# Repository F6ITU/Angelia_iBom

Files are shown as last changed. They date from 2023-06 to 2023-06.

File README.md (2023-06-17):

# Angelia_iBom
Kicad iBom for OpenHPSDR Angelia SDR main board (reversing)

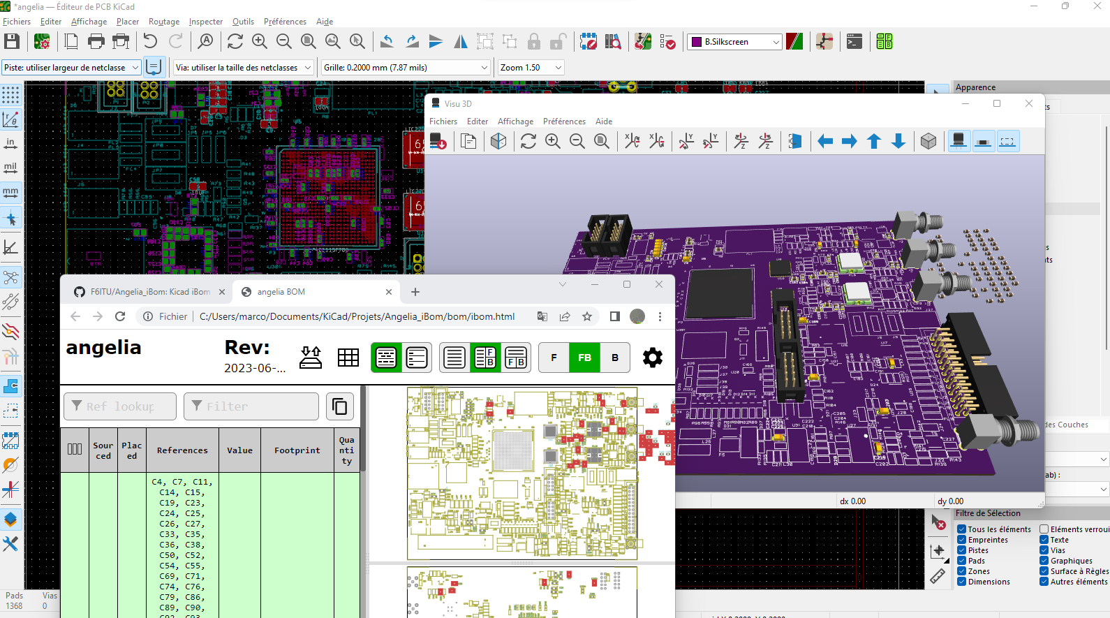
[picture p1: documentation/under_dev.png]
Kicad iBom for OpenHPSDR Angelia


This repository is dedicated to all people wishing to home-built the OpenHPSDR Angelia board. 

This reversing has been done using the official BOM, the original silkmask and the schematic made by the OpenHPSDR group

As most of HPSDR design have been made with a close source EDA (probably Altium), it was necessary to offer an open hardware kind of help 
to the rare and brave people who had the chance to get a grip on a bare Angelia board

This iBom is not fully documented, obvious component placement have been ommited. Feel free to complete the job if you feel yourself 
brave enough 

the 3D picture below gives an idea of the progression
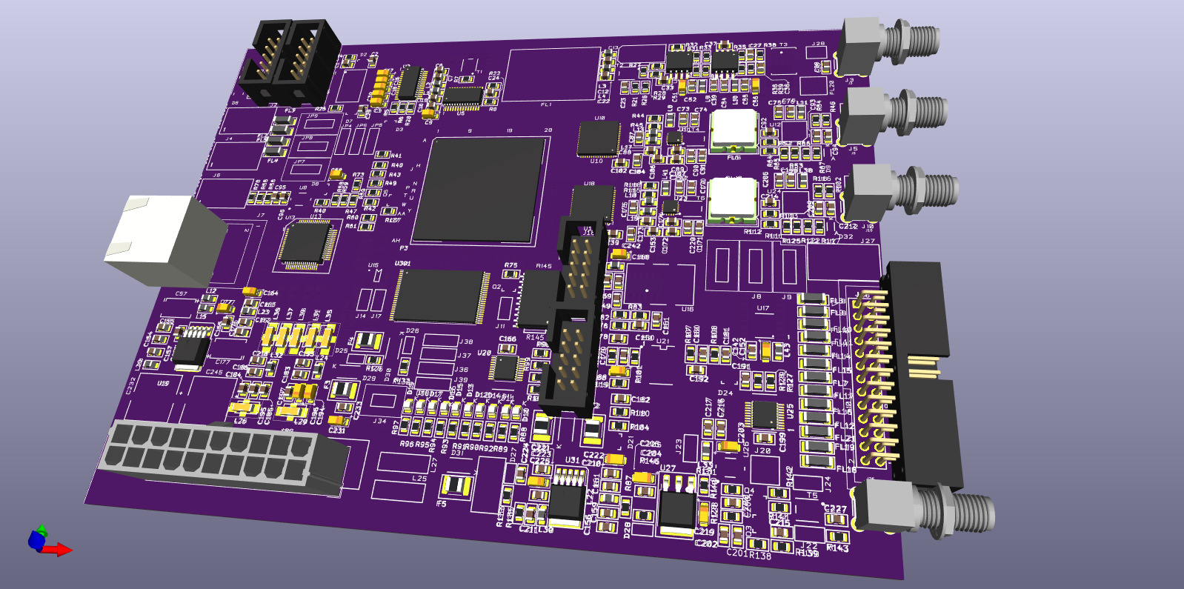
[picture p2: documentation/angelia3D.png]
Kicad angelia virtual board, OpenHPSDR


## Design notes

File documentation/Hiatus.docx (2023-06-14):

Hiatus : C70 absente de la bom, présente silk, sur adc0

Jumelle de C238, 100nF// C 104 ? sur le schéma

C201 placé à coté de C202 comme sur schéma, mais pas de silk pour confirmer

Vérifier C73 C74 et miroir du coté des antialiasing

C201 ??? R138 ??? (138 non marqué, mais très probable)

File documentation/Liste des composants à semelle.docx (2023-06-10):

Liste des composants à semelle, Angelia

FPGA

U21 : TPA0202

U10, U18 : LTC2208CUP (lab)

U11, U23 : LTC6400-20 (lab)

U12, U24 : DAT-31-SP+ (yannick)

U13 : KSZ9021RL

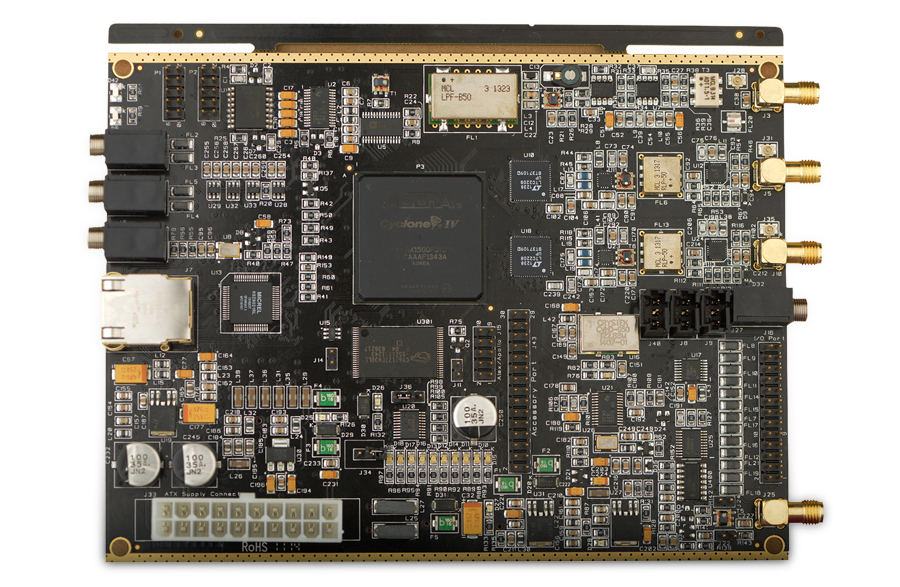
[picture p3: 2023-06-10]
documentation/angelia.jpg

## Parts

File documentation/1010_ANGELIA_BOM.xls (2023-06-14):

Copyright 2012- Apache Labs Pvt Ltd, Angelia Production BOM
Item | CODE | Quantity | Part Number | Reference | format | Part | Manufacturer | Vendor | Vendor Part number | Large Qty no. | remarque | prix | distrib | ref dist. | alternate
1 | A0001 | 30 | T491A106M020AT | C3,C5,C8,C9,C16,C17,C18,C20,C21,C30,C31,C51,C56,C58, C77,C78,C125,C152,C164,C168,C188,C194,C196,C203,C207,C219,C223,C228,C229,C231 | 1206 Kemet T491 | 10UF | Kemet | DigiKey | 399-5152-2-ND | 399-5152-2-ND
2 | A0002 | 80 | C0805X104K1RACTU | C4,C7,C11,C14,C15,C19,C23,C24,C25,C26,C27,C33,C35,C36,C38,C50,C52,C54,C55,C69,C71,C74,C76,C79,C86,C89,C90,C92,C93,C94,C96, C97,C104,C106,C111,C124,C142,C145,C148,C153,C154,C155,C156,C158,C161,C163,C166,C169,C171,C174,C182,C183,C189,C190,C192,C193,C197,C198,C199,C200,C202,C204,C209,C211,C212,C214,C215,C216,C218,C225,C226,C227,C230,C233,C235,C237,C238,C240,C244,C292 | 0805 | 100NF | Kemet | DigiKey | 399-5333-1-ND | 399-5333-2-ND | 80 pieces (par 500 pcs) | 33,5 € | RS | RS 869-5886
3 | A0118 | 2 | 652-CDSOD323-T05LC | D9,D32 | SOD323 | 652-CDSOD323-T05LC | Bourns | Mouser | 652-CDSOD323-T05LC
4 | A0003 | 17 | EXC-CET102U | FL2,FL3,FL4,FL5,FL7,FL8,FL9,FL10,FL11,FL12, FL14,FL15,FL16,FL17,FL18,FL19,FL21 | 1807 | INDUCTOR AUDIO | Panasonic | DigiKey | P9830CT-ND | P9830TR-ND | obsolete
5 | A0004 | 4 | AISC-0805-R047J-T | L13, L17,L18, L19 | 0805 | 47NH | Abracon | DigiKey | 535-10497-1-ND | 535-10497-2-ND
6 | A0005 | 4 | 08055A100JAT2A | C1,C2,C28,C29 | 0805 | 10PF | AVX | DigiKey | 478-1304-1-ND | 478-1304-2-ND
7 | A0006 | 36 | GRM21BR72A103KA01L | C6,C10,C53,C85,C91,C95,C102,C108,C109,C110,C112,C113,C114,C126,C127,C128,C129,C141,C143,C144,C146,C147,C151,C157,C159,C160,C162,C167,C201,C208,C217,C220,C234,C236,C241,C243 | 0805 | 10NF | Murata | DigiKey | 445-1348-1-ND | 445-1348-2-ND
8 | A0007 | 1 | GRM2165C2A201JA01D | C12 | 805 | 200PF | Murata | DigiKey | 490-1606-1-ND | 490-1606-2-ND
9 | A00112 | 1 | SG2020CT-ND | C13 | CV cms | 20PF | Sprague | DigiKey | SG2020CT-ND | SG2020TR-ND
10 | A0008 | 1 | 08055A150JAT2A | C22 | 0805 | 15PF | AVX | DigiKey | 478-1306-1-ND | 478-1306-2-ND
11 | A0009 | 3 | B45197A5476K409 | C32,C57,C177 | 2917 Kemet T495 | 47UF | Kemet | DigiKey | 495-1571-1-ND | 495-1571-2-ND
12 | A0010 | 2 | 08055A330JAT2A | C37,C39 | 0805 | 33PF | AVX | DigiKey | 478-1310-6-ND | 478-1310-2-ND
13 | A0011 | 8 |  | C40,C49,C60,C62,C80,C100,C132,C133 | 0402 | 1NF 0402 | TDK | DigiKey | 445-1256-1-ND | 445-1256-2-ND
14 | A0012 | 33 |  | C41,C43,C44,C45,C46,C47,C48,C61,C63,C64,C65,C66,C67,C68,C81,C83,C84,C98,C99,C101,C115,C116,C117,C118,C119,C120,C122,C123,C134,C135,C137,C138,C139 | 0402 | 100NF 0402 | TDK | DigiKey | 445-4952-1-ND | 445-4952-2-ND | par 500 | 7 | RS | RS 741-4415
15 | A0013 | 8 |  | C42,C59,C82,C121,C130,C131,C136,C140 | 0402 | 10NF 0402 | TDK | DigiKey | 445-1260-1-ND | 445-1260-2-ND
16 | A0014 | 6 | C2012C0G1H102J | C70,C103,C179,C180,C239,C242 | 0805 C0G | 1NF(1000PF) | TDK | DigiKey | 445-1330-1-ND | 445-1330-2-ND
17 | A0014 | 6 | C2012C0G1H102J | C72,C73,C107,C170,C172,C251 | 0805 C0G | 1000PF | TDK | DigiKey | 445-1330-1-ND | 445-1330-2-ND
18 | A0016 | 6 | C0805C101J5GACTU | C75,C87,C105,C173,C175,C206 | 0805 C0G | 100PF | Kemet | DigiKey | 399-1122-1-ND | 399-1122-2-ND
19 | A0017 | 2 | TMK212B7225KG-TR | C88,C213 | 0805 | 2.2UF | Taiyo Yuden | DigiKey | 587-2991-2-ND | 587-2991-2-ND
20 | A0018 | 1 | GRM21BR71E334KA01L | C149 | 0805 | 330NF | Murata | DigiKey | 490-1677-1-ND | 490-1677-2-ND
21 | A0019 | 1 | 08055C473KAT2A | C150 | 0805 | 47NF | AVX | DigiKey | 478-1391-1-ND | 478-1391-2-ND
22 | NR | 7 | EMK212BJ106KG-T | C165,C176,C178,C181,C184,C186,C195 | 0805 | 10UF | TDK | DigiKey | 445-7534-1-ND | 445-7534-2-ND | la référence digikey est celle de 100 nF
23 | NR | 1 |  | C185 | 0805 | (10UF) | Murata | DigiKey | 478-1391-1-ND | 478-1391-2-ND | la référence digikey est celle de 470 nF
24 | A0022 | 4 |  | C187,C210,C221,C224 | 0805 | 1UF | TDk | DigiKey | 445-1354-1-ND | 445-1354-2-ND
25 | A0023 | 1 | GRM2165C1H471JA01D | C191 | 0805 | 470PF | Murata | DigiKey | 490-1617-1-ND | 490-1617-2-ND
26 | A0024 | 2 | TAJA105K025RNJ | C205,C222 | 1206 | 1UF | AVX | DigiKey | 478-2363-1-ND | 478-2363-2-ND
27 | A0120 | 2 |  | C232,C245 | 0.394" Dia (10.00mm) | 100UF | Panasonic | DigiKey | PCE3949TR-ND | PCE3949TR-ND
28 | A0025 | 2 | BAT54C-G | D2,D7 | SOT23 | BAT54C | Comchip | DigiKey | 641-1320-1-ND | 641-1320-2-ND
29 | A0026 | 1 | BAT54S-TP | D3 | SOT23 | BAT54S | Micro Commercial | DigiKey | BAT54STPMSCT-ND | BAT54STPMSTR-ND
30 | A0027 | 3 | BAT54-TP | D4,D5,D24 | SOT23 | BAT54 | Micro Commercial | DigiKey | BAT54TPMSCT-ND | BAT54TPMSTR-ND
31 | A0028 | 2 | LS Y876-Q2S1-1-Z | D6,D42 | 2-SMD, Flat Lead | FRONT LED | Osram | DigiKey | 475-2769-1-ND | 475-2769-2-ND
32 | A0029 | 1 | BAT54A-G | D8 | SOT23 | BAT54A/SOT | Comchip | DigiKey | 641-1319-1-ND | 641-1319-2-ND
33 | A0030 | 10 | APT2012SURCK | D10,D11,D12,D13,D14,D15,D16,D17,D18,D19 | 0805 (led) | RED LED | Kingbright | DigiKey | 754-1133-1-ND | 754-1133-2-ND
34 | A0031 | 4 | MBRA340T3G | D20,D29,D30,D31 | DO-214AC, SMA | MBRA340T3G | ON Semi | DigiKey | MBRA340T3GOSCT-ND | MBRA340T3GOSTR-ND
35 | A0032 | 1 | BZX84C3V3-TP | D21 | SOT23-3 | BZX84C 3V3 | Diodes Inc | DigiKey | BZX84C3V3-FDICT-ND | BZX84C3V3-FDITR-ND
36 | A0033 | 4 |  | D25,D26,D27,D28 | 0805 | GREEN LED | Lite-On | DigiKey | 160-1423-1-ND | 160-1423-2-ND
37 | A00121 | 1 |  | FL1 | : HZ1198 | LPF-B50+ |  | MCL | LPF-B50+ | LPF-B50+ |  | 16,95 $ | MCL
38 | A00125 | 2 | RLP-50+ | FL6,FL13 | GP731 | RLP-50+ |  | MCL | RLP-50+ | RLP-50+ |  | 7,95 $ | MCL
39 | A00127 | 1 | LFCV-52+ | FL20 | JV1210C | LFCV-52+ |  | MCL | LFCV-52+ | LFCV-52+ |  | 3,99 $ | MCL
40 | A0034 | 4 |  | F1,F2,F4,F5 | 1812 | 2A FUSE | Bel Fuse | DigiKey | 507-1508-1-ND | 507-1508-2-ND | change selon protocol 2
41 | A00113 | 7 |  | JP4,JP5,JP6,J36,J37,J38,J39 |  | 3 PIN BERG | Molex | Digikey | 609-3461-ND | 609-3461-ND
42 | A0035 | 5 |  | JP7,JP8,J8,JP9,J9 |  | 3 PIN CONNECTOR | TE | DigiKey | A28477-ND | A28477-ND
43 | A0036 | 4 |  | J2,J4,J6,J27 |  | 3.5MM AUDIO | CUI | DigiKey | CP1-3533N-ND | CP1-3533N-ND
44 | A0037 | 4 |  | J3,J5,J10,J25 | SMA Angle | SMA | TE | DigiKey | A97593-ND | A97593-ND
45 | A0038 | 1 |  | J7 | RJ45 (voir hermeslite) | RJ45 | TE Connectivity | DigiKey | A99638-ND | A99638-ND |  | 12,41 $ | DGK |  | Farnell (ref alternative 1572188
46 | A0039 | 6 |  | J11,J14,J17,J22,J23,J24 |  | HEADER 2 | FCI | DigiKey | 609-4434-ND | 609-4434-ND
47 | A0040 | 4 |  | P1,P2,J15,J18 |  | 5X2 BERG | FCI | DigiKey | 609-3458-ND | 609-3458-ND
48 | A00111 | 1 | DNI | J16 |  | IO HEADER | FCI | DigiKey | 609-3240-ND | 609-3240-ND
49 | A0039 | 1 |  | J20 |  | JUMPER 10Mhz SELECT | FCI | DigiKey | 609-4434-ND
50 | A0042 | 3 |  | J28,J31,J35 | ufl | MICRO COAXIAL | Molex | DigiKey | WM5587CT-ND | WM5587CT-ND
51 | A0043 | 1 |  | J33 | conn ATX | ATX Connector | Molex | DigiKey | WM7346-ND | WM7346-ND
52 | NR | 1 | DNI | J34 |  | POWER SWITCH
53 | A00113 | 1 |  | J40 (PCB LOCATION NOT FOUND) |  | CLK OUT
54 | A0044 | 25 |  | L1,L2,L6,L8,L9,L10,L11,L12,L14,L15,L16,L20,L21,L22,L23,L24,L30,L32,L33,L38,L41,L42,L43,L44,L45 | 0805 | MPZ2012S221A | TDK | DigiKey | 445-1568-1-ND | 445-1568-2-ND
55 | A0045 | 1 |  | L3 | 0805 | 560nH 5% | Panasonic | DigiKey | PCD1181CT-ND |  | obsolete r (qtt 5==> | 0,576 € | RS | 871-1985 | NFM41PC204F1H3L
56 | A0046 | 1 |  | L4 | 0805 | 22nH | Sumida | DigiKey | 308-1733-1-ND | 308-1733-1-ND | non stocké
57 | NR | 2 |  | L25,L27 | 2-SMD, J-Lead | 2743021447 | Fair-Rite | Mouser | 623-2743021447LF
58 | A0047 | 7 |  | L26,L29,L31,L35,L36,L37,L39 | 1806 | NFM41PC204F1H3L | Murata | DigiKey | 490-2550-1-ND | 490-2550-2-ND
59 | A0128 | 1 |  | P3 | 780FBGA | EP4CE115F780 | Altera | DigiKey | 544-1471-ND | 544-1471-ND | faible stock dgk | 341,36 $ |  |  | mouser farnell avnet
60 | A0048 | 2 |  | Q2,Q5 | SOT23-3 | 2N7002K | Fairchild | DigiKey | 2N7002KCT-ND | 2N7002KTR-ND
61 | A0049 | 2 |  | Q3,Q4 | SOT23-3 | MMBT3906 | Diodes Inc | DigiKey | MMBT3906-FDICT-ND | MMBT3906-FDITR-ND
62 | A0050 | 36 |  | R2,R10,R40,R41,R42,R50,R52,R53,R54,R58,R64,R65,R66,R67,R68,R69,R70,R71,R72,R75,R78,R82,R106,R108,R111,R112,R113,R114,R116,R117,R122,R123,R124,R125,R136,R137 | 0805 | 10K | Vishay | DigiKey | 541-10.0KCCT-ND | 541-10.0KCTR-ND
63 | A0051 | 16 |  | R3,R16,R21,R26,R43,R48,R49,R61,R79,R85,R103,R109,R120,R121,R130,R133 | 0805 | 1K | Vishay | DigiKey | 541-1.00KCCT-ND | 541-1.00KCTR-ND
64 | A0052 | 6 |  | R4,R25,R28,R29,R33,R34 | 0805 | 22E | Vishay | DigiKey | 541-22.0CCT-ND | 541-22.0CTR-ND
65 | A0053 | 13 |  | R5,R6,R88,R89,R90,R91,R92,R93,R94,R95,R96,R97,R132 | 0805 | 2K2 | Panasonic | DigiKey | P2.20KCCT-ND | P2.20KCTR-ND
66 | A0054 | 7 |  | R7,R44,R45,R115,R118, R141,R143 | 0805 | 51E | Yageo | DigiKey | 311-51ARCT-ND | 311-51ARTR-ND
67 | A0055 | 1 |  | R8 | 0805 | 1K8 | Vishay | DigiKey | 541-1.80KCCT-ND | 541-1.80KCTR-ND
68 | A0056 | 1 |  | R9 | 0805 | 18K | Vishay | DigiKey | 541-18.0KCCT-ND | 541-18.0KCTR-ND
69 | A0057 | 2 |  | R11,R12 | 0805 | 510K | Vishay | DigiKey | 541-510KCCT-ND | 541-510KCTR-ND
70 | A0058 | 3 |  | R13,R14,R15 | 0805 | 100K | Vishay | DigiKey | 541-100KCCT-ND | 541-100KCTR-ND
71 | A0059 | 2 |  | R19,R51 | 0805 | 1K5 | Vishay | DigiKey | 541-1.50KCCT-ND | 541-1.50KCTR-ND
72 | A0060 | 5 | CRCW08053K30FKEA | R20,R76,R129,R138,R140 | 0805 | 3K30 | Vishay | DigiKey | 541-3.30KCCT-ND | 541-3.30KCTR-ND
73 | A0061 | 2 |  | R22,R24 | 0805 | 100E | Vishay | DigiKey | 541-100CCT-ND | 541-100CTR-ND
74 | A0062 | 1 |  | R23 | 0805 | 220K | Panasonic | DigiKey | P220KCCT-ND | P220KCTR-ND
75 | A0063 | 1 |  | R27 | 0805 | 200E | Vishay | DigiKey | 541-200CCT-ND | 541-200CTR-ND
76 | A0064 | 2 |  | R30,R31 | 0805 | 330E | Vishay | DigiKey | 541-330CCT-ND | 541-330CTR-ND
77 |  | 4 |  | R32,R55,R56,R127 | 0805 | 220E | Vishay | DigiKey | 541-180CCT-ND | 541-180CTR-ND
78 | A0066 | 4 |  | R35,R36,R37,R146 | 0805 | 470E | Vishay | DigiKey | 541-470CCT-ND | 541-470CTR-ND
79 | A0067 | 2 |  | R38,R39 | 0805 | 4.7E | Vishay | DigiKey | 541-4.70CCCT-ND | 541-4.70CCTR-ND
80 | A0068 | 2 |  | R46,R102 | 0805 | 1M | Vishay | DigiKey | 541-1.00MCCT-ND | 541-1.00MCTR-ND
81 | A0069 | 9 |  | R47,R60,R77,R84,R86,R87,R119,R131,R135 | 0805 | 0E | Vishay | DigiKey | 541-0.0ACT-ND | 541-0.0ATR-ND
82 | A0070 | 1 |  | R57 | 0805 | 4K99 | Vishay | DigiKey | 541-4.99KCCT-ND | 541-4.99KCTR-ND
83 | A0071 | 3 |  | R59,R73,R104 | 0805 | 4K7 | Vishay | DigiKey | 541-4.70KCCT-ND | 541-4.70KCTR-ND
84 | A0072 | 3 |  | R83,R101,R107 | 0805 | 47K | Vishay | DigiKey | 541-47.0KCCT-ND | 541-47.0KCTR-ND
85 | A0073 | 4 |  | R98,R99,R100,R105 | 0805 | 33E | Vishay | DigiKey | 541-33.0CCT-ND | 541-33.0CTR-ND
86 | A0074 | 2 |  | R110,R126 | 0805 | 820E | Vishay | DigiKey | 541-820CCT-ND | 541-820CTR-ND
87 | A0075 | 0 |  |  | 0805 | 6K8 | Vishay | DigiKey | 541-6.80KCCT-ND | 541-6.80KCTR-ND
88 | A0076 | 1 |  | R142 | 0805 | 150E | Panasonic | DigiKey | P150CCT-ND | P150CCT-ND
89 | A0077 | 1 |  | R145 | 20SOIC | SOMC100KPCT-ND | Vishay | DigiKey | SOMC100KPCT-ND | SOMC100KPCT-ND
90 | A00123 | 2 |  | T1,T5 | AT224-1A | TC1-1T | MCL | MCL | TC1-1T+ | TC1-1T+ |  | 2,19 $ | MCL
91 | A00122 | 3 |  | T2,T4,T6 | AT224-1A | TC4-1T | MCL | MCL | TC4-1T+ | TC4-1T+ |  | 2,19 $ | MCL
92 | A00126 | 1 |  | T3 | AT224-1A | ADT1.5-1 | MCL | MCL | ADT1.5-1+ | ADT1.5-1+ |  | 14,95 $ | MCL
93 | A00129 | 1 |  | U1 |  | EPCS128 | ALTERA | plusieurs | ref, attention | EPCS128 | EPCS64 REC
94 | A0078 | 1 |  | U2 | 28-TSSOP | TLV320AIC23B | TI | Digikey | 296-15031-1-ND | 296-15031-1-ND | samples TI | 8.69 $ | DGK
95 | A0079 | 2 |  | U3,U4 | 8SOIC | LMC6482AM | National | DigiKey | LMC6482IM-ND | LMC6482IM-ND |  | 1,19 € | rs-comp | RS 534-4153 | arrow
96 | A0080 | 1 |  | U5 | 28TSSOP | AD9744ARU | AD | DigiKey | AD9744ARUZ-ND | AD9744ARUZ-ND | fin de vie | 17,67 $ | DGK |  |  | attention, composant rare
97 | A0081 | 2 |  | U6,U7 | 8SOIC | OPA2674IC | TI | DigiKey | 296-15212-5-ND | 296-15212-5-ND | samples TI | 4,15 $ | DGK
98 | A0117 | 1 |  | U8 | 4-SMD, No Lead (tcxo) | 25MHZ | Fox | DigiKey | 631-1074-1-ND | 631-1074-2-ND |  | 2,71 $ | DGK |  | Farnell, elt 14
99 | A0084 | 2 |  | U10,U18 | 64QFN | LTC2208CUP | LTC2208CUP | NU HORIZON | LTC2208CUP#PBF | LTC2208CUP#PBF-ND | samples LT
100 | A0085 | 2 |  | U11,U23 | 16QFN | LTC6400-20 | LTC6400-20 | NU HORIZON | LTC6400CUD-20#PBF | LTC6400CUD-20#PBF-ND | samples LT
101 | A00124 | 2 |  | U12,U24 | DG983-2 (qfn 20) | DAT-31-SP+ | MCL | MCL | DAT-31-SP+ | DAT-31-SP+ | DAT-31A-SP+ | 3,55 $ | MCL |  |  | This is a non-catalog model
102 | A0086 | 1 |  | U14 | 14SOIC | SN65LVDM180D | TI | DigiKey | 296-1420-5-ND | 296-1420-5-ND |  | 3,39$ | DGK |  | Farnell mouser
103 |  | 1 |  | U15 | SOT23-6 | 25AA02E48T-I/OT | Microchip | DigiKey | 25AA02E48T-I/OTCT-ND | 25AA02E48T-I/OTCT-ND |  | 0,32€ | rs-comp | RS 667-8347
104 | A0088 | 1 |  | U16 | oscillateur crystek | 122.88MHZ | Crystek | DigiKey | 744-1271-ND | 744-1271-ND |  | 33,46 $ | DGK |  | mouser 549-CVHD-950-122.880 (22,9 € | remplacé par CVHD-37x
105 | A0089 | 1 |  | U17 | 16-TSSOP large? | ADC78H90CIMT | National | DigiKey | ADC78H90CIMT-ND | ADC78H90CIMT-ND | samples TI | 6,31€ | Farnell | 2496158 |  | rupure
106 | A0090 | 2 |  | U19,U31 | TO-252-5, DPak (4 Leads + Tab), TO-252AD | LD49300PT12R | STM | DigiKey | 497-8277-1-ND | 497-8277-1-ND |  | 2,32 $ | DGK |  | mouser
107 | A0091 | 2 |  | U20,U25 | 20TSSOP | 74LCX541 | Fairchild | DigiKey | 74LCX541MTC-ND | 74LCX541MTCXTR-ND |  | 0,38 € | rs-comp |  | qté de 10
108 | A0092 | 1 |  | U21 | 24HTSSOP | TPA0202 | TI | DigiKey | 296-1940-5-ND | 296-1940-5-ND |  | 4,45 $ | DGK |  | Mouser, TI store
109 | A0093 | 1 |  | U22 | SOIC 16 | ULN2003AD | TI | DigiKey | 296-1368-5-ND | 296-1368-2-ND |  |  |  |  | voir RS, en qté
110 | A0094 | 1 |  | U24 -U13? | 64-LQFP-EP | KSZ9021RL | Micrel | DigiKey | 576-3636-ND | 576-3636-ND |  | 9,77€ | rs-comp | RS 911-2717
111 | A0095 | 1 |  | U26 | xtal idem | 10MHZ 3.2X5MM | Fox | DigiKey | 631-1067-1-ND | 631-1067-2-ND |  | 2,34 $ | DGK |  | farnell mouser
112 | A0096 | 1 |  | U27 | TO252-3 | LD1117-2.5V | Diodes Inc | DigiKey | ZLDO1117K25DICT-ND | ZLDO1117K25DICT-ND |  | 0,59 $ | DGK |  | mouser
113 | A0097 | 1 |  | U301 | 48-TFSOP | CY62177EV30LL-55ZXI-ND | CY62177EV30LL-55ZXI | ARROW | CY62177EV30LL-55ZXI | CY62177EV30LL-55ZXI-ND |  | 35,35€ | rs-comp | RS 726-0209
114 | A0098 | 1 |  | F3 | 1812 | O0ZCC0300FF2B | O0ZCC0300FF2B | BEL FUSE | 507-1513-1-ND | 507-1513-1-ND
 |  | 2 |  | R128, R139 |  | 5K11 |  |  |  |  | probablement ligne 87
 |  | 556

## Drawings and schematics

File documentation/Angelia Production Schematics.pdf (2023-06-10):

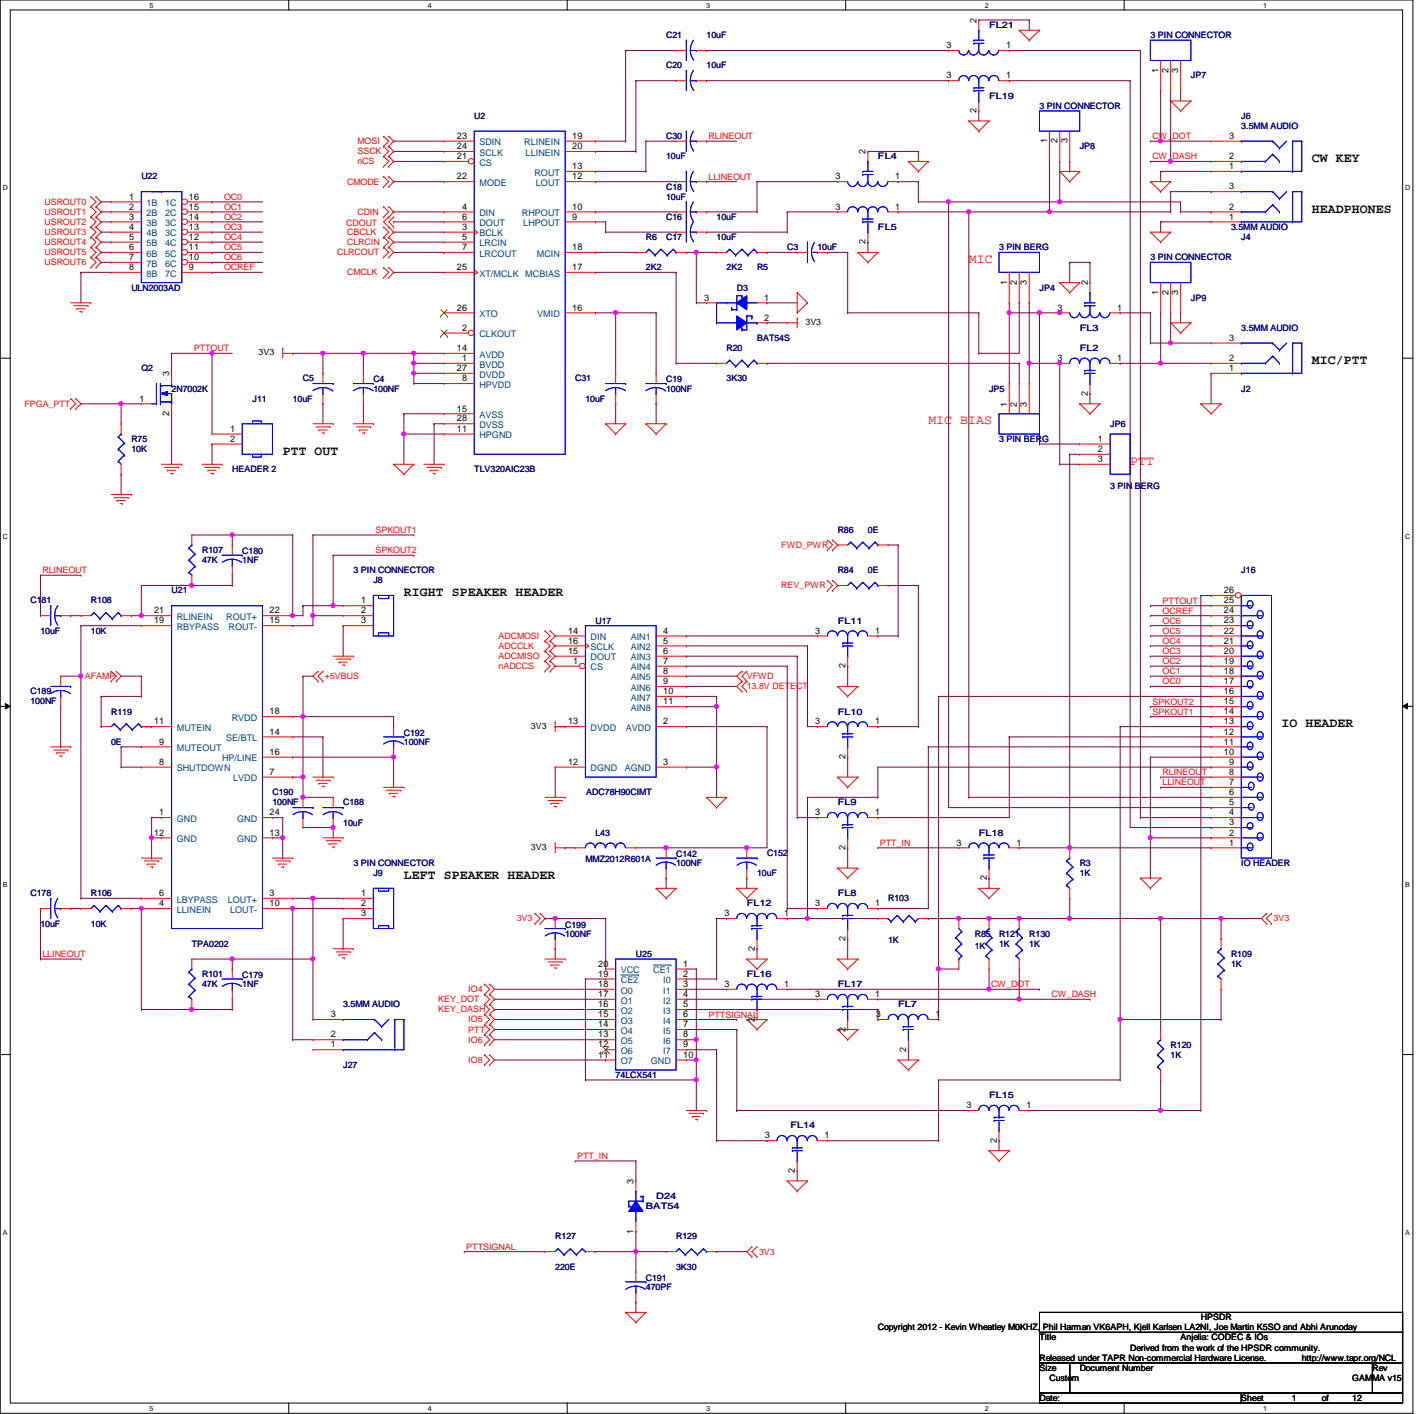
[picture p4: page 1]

Copyright 2012 - Kevin Wheatley M0KHZ, Phil Harman VK6APH, Kjell Karlsen LA2NI, Joe Martin K5SO and Abhi Arunoday

Derived from the work of the HPSDR community.

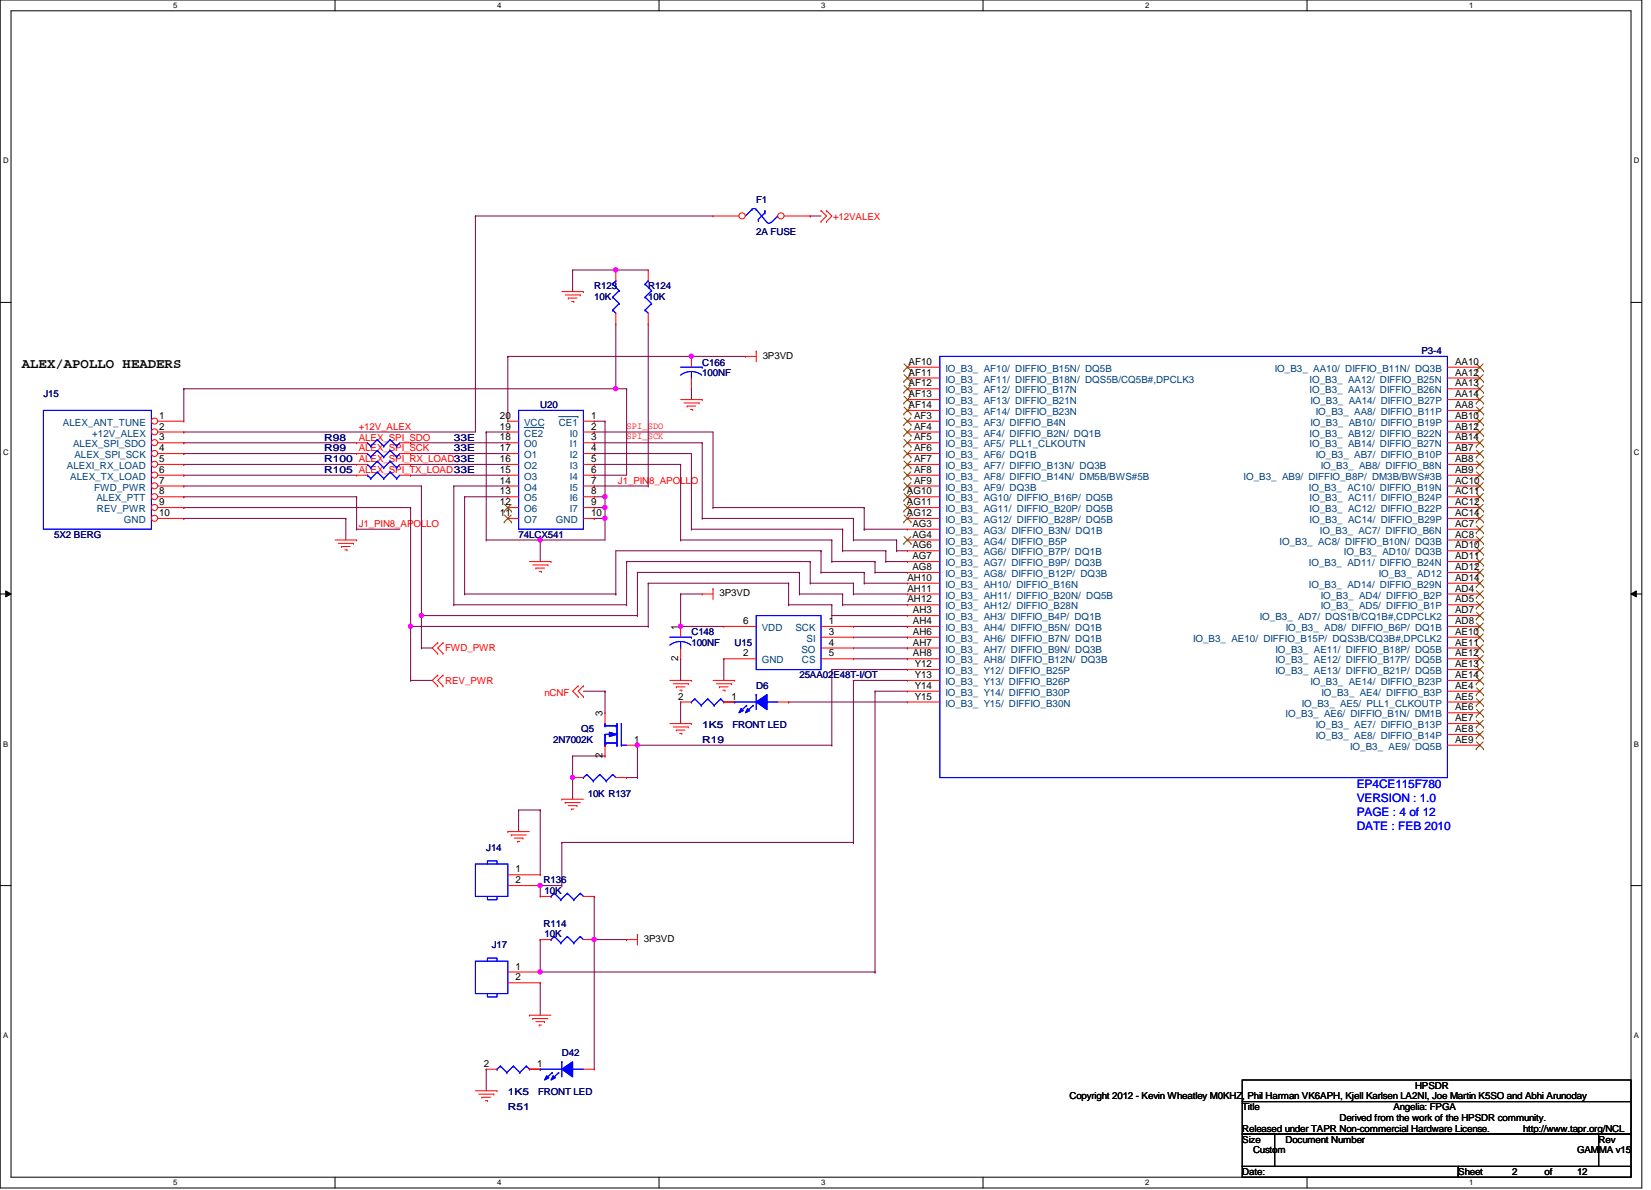
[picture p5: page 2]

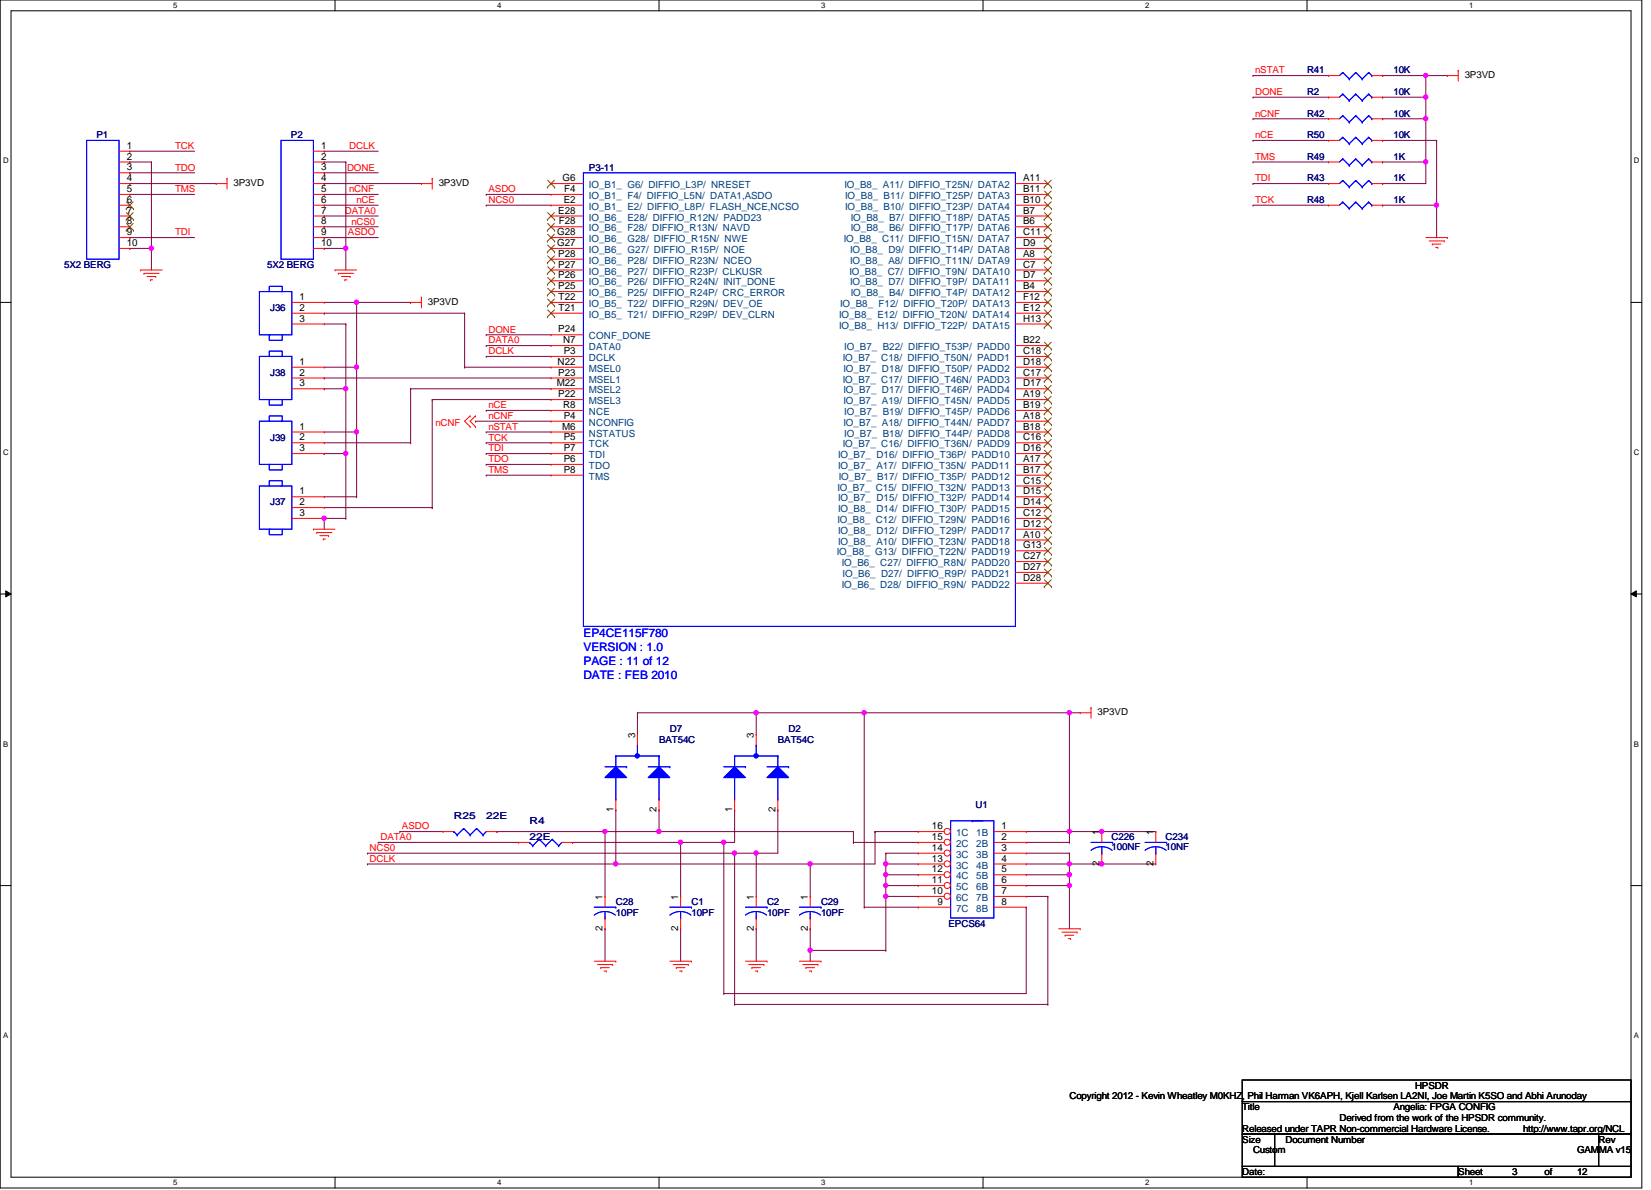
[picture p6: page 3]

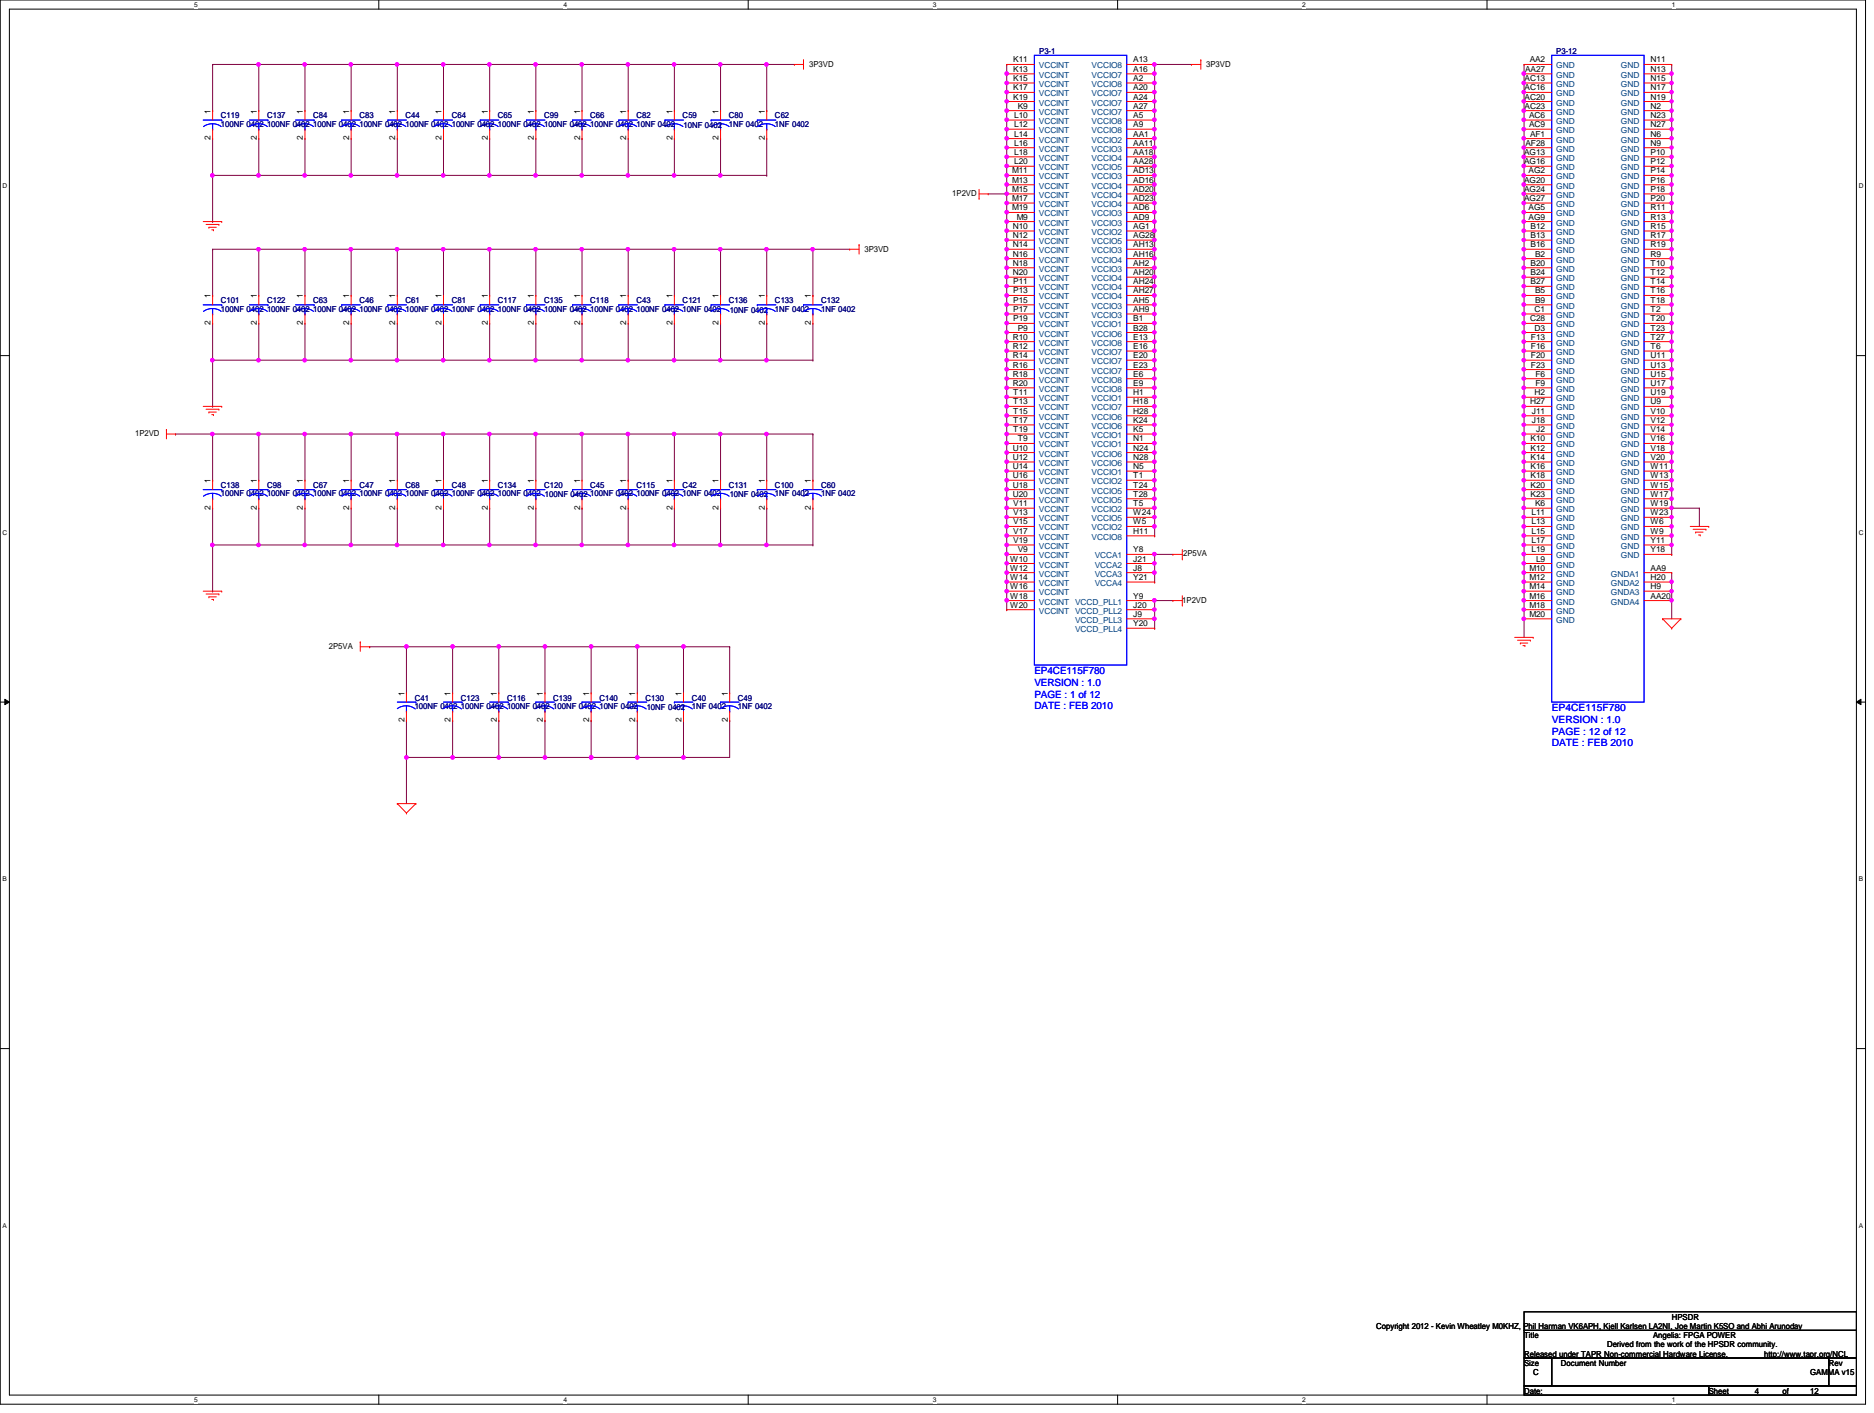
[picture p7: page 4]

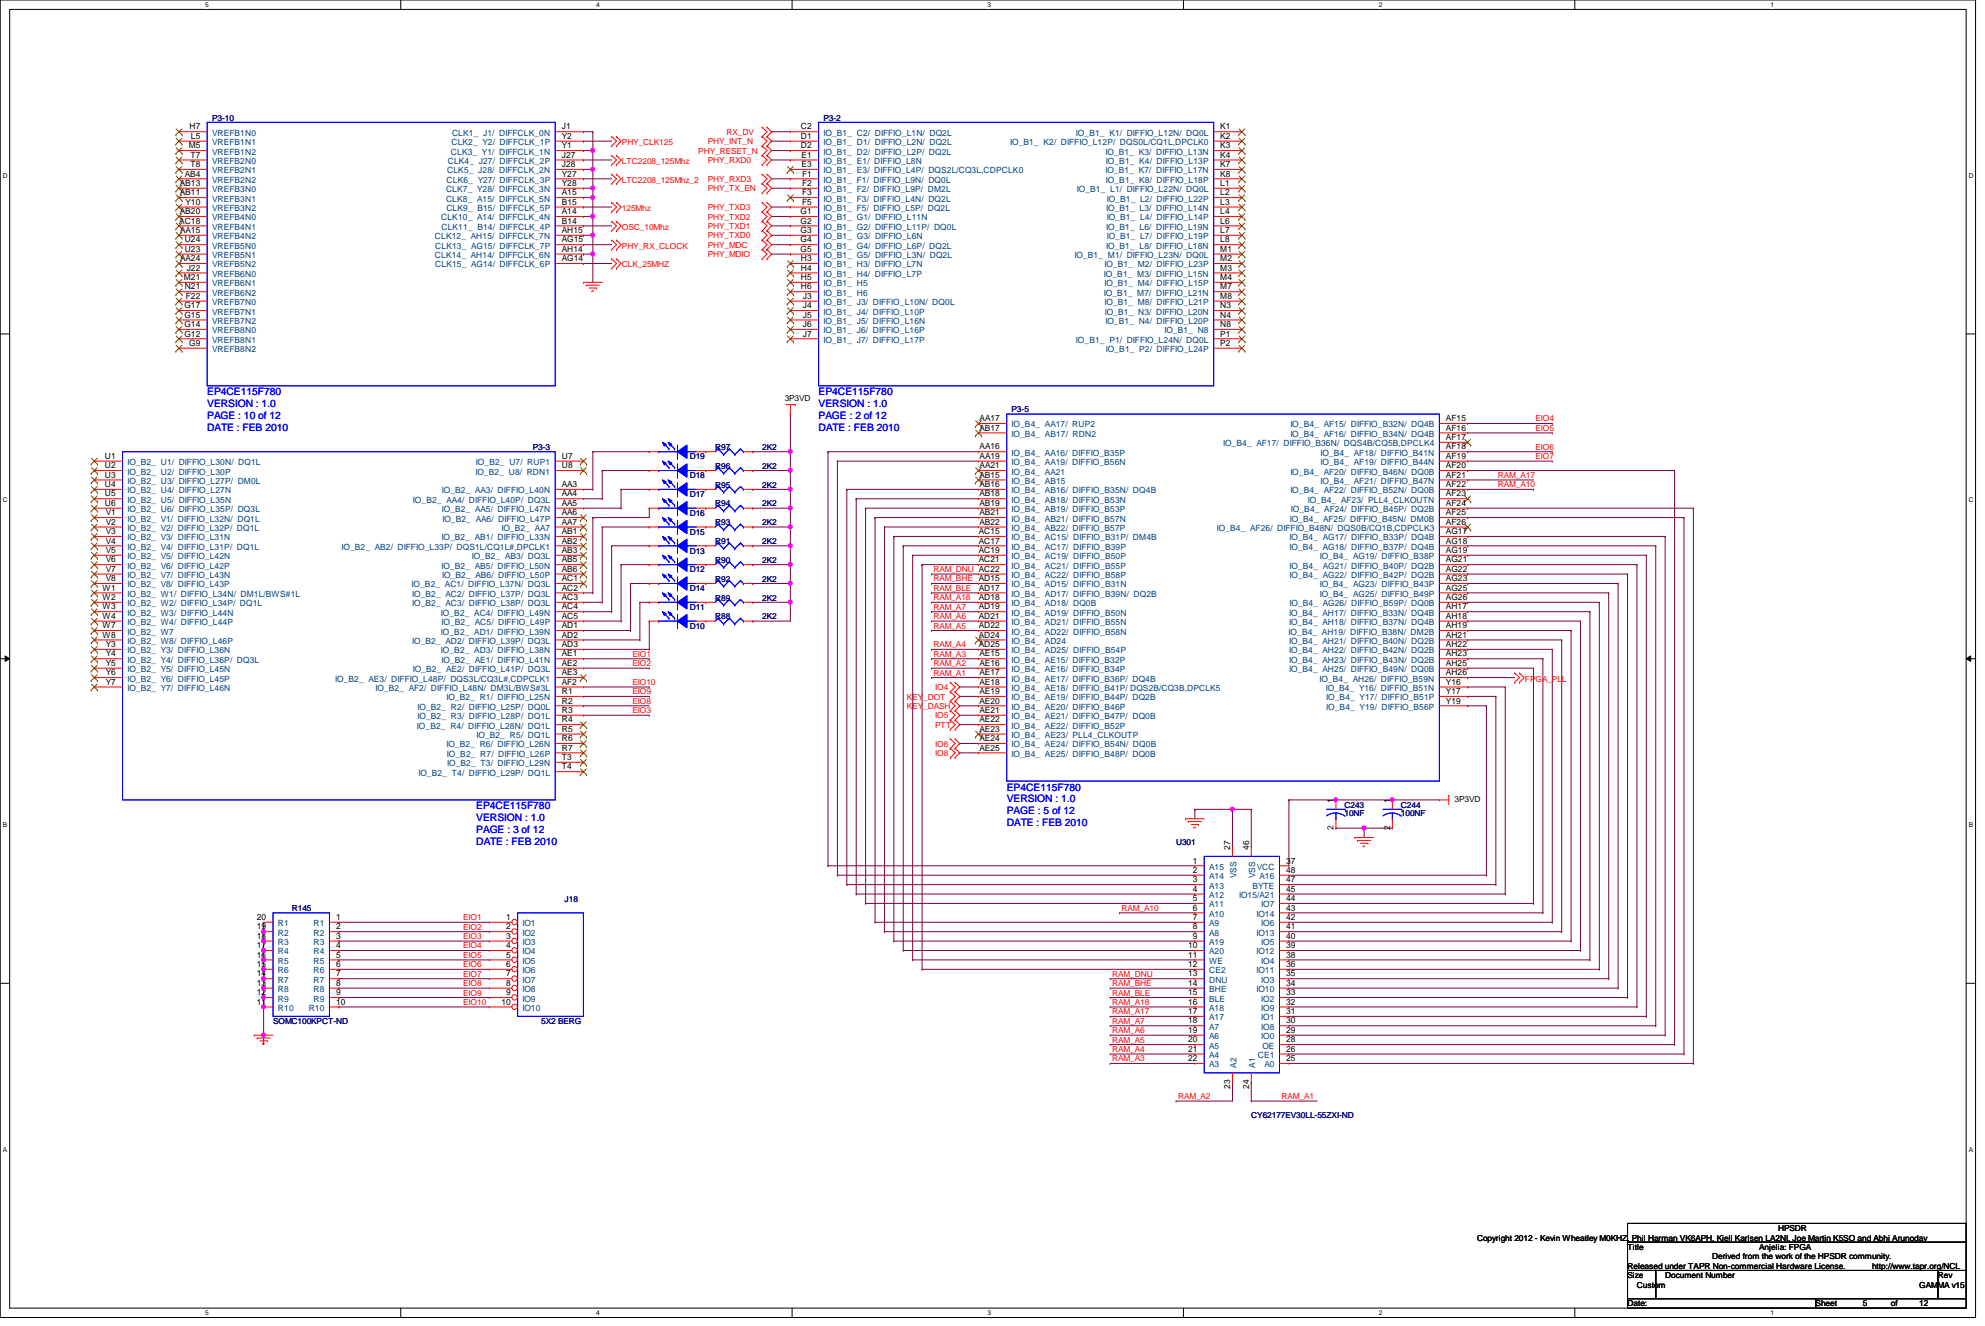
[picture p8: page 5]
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

Derived from the work of the HPSDR community.

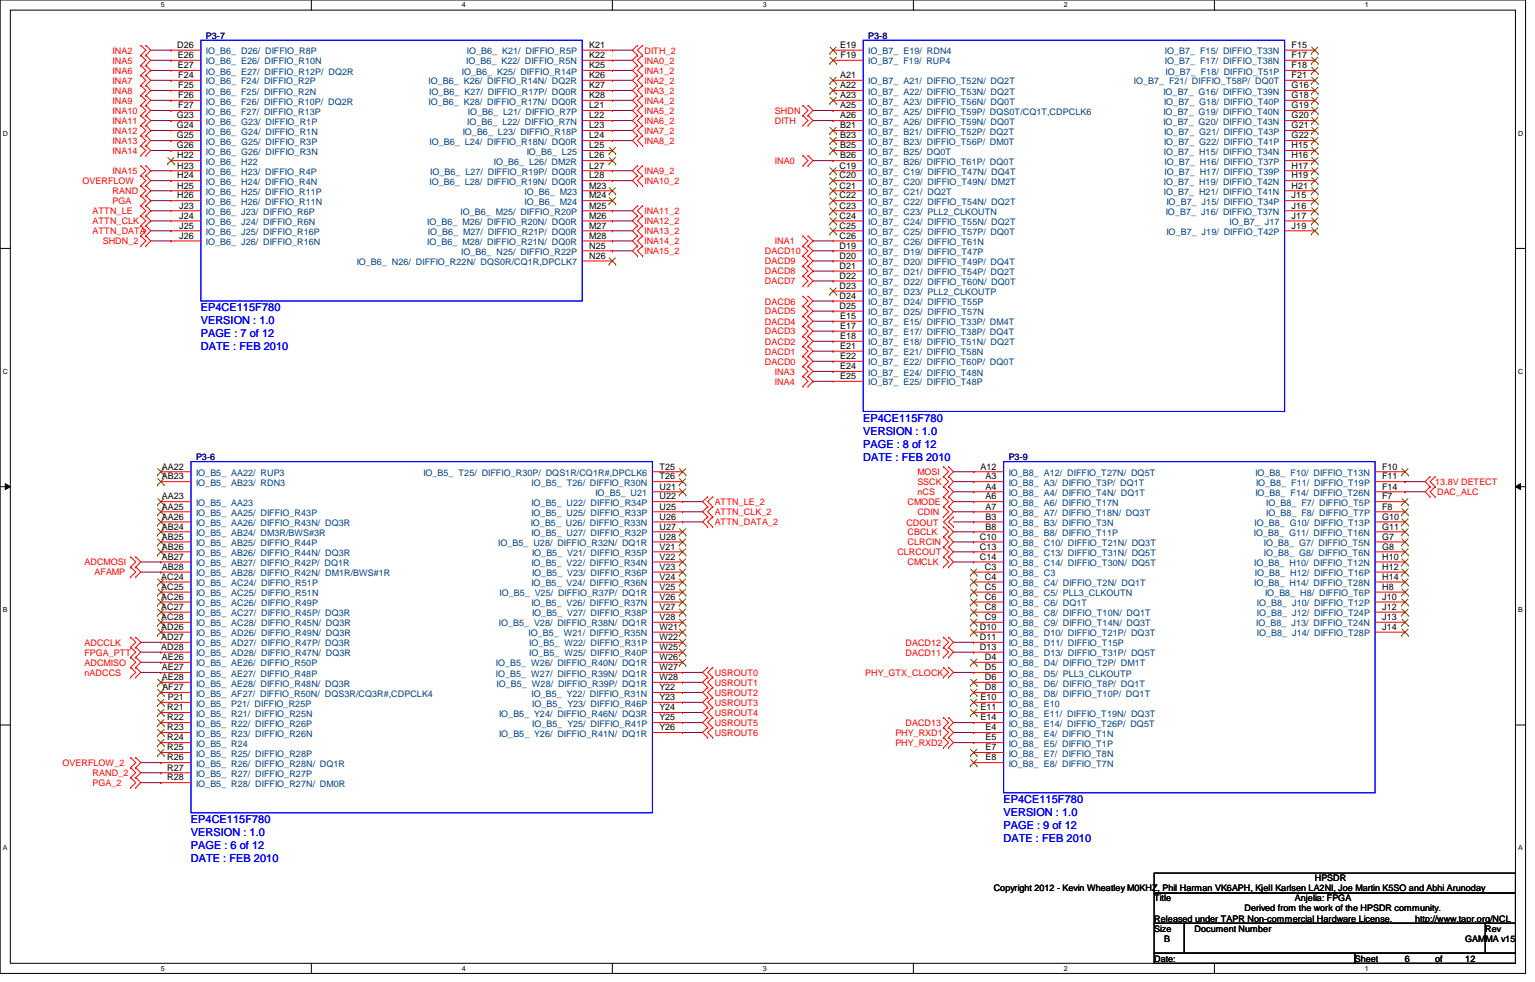
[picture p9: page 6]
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

Derived from the work of the HPSDR community.

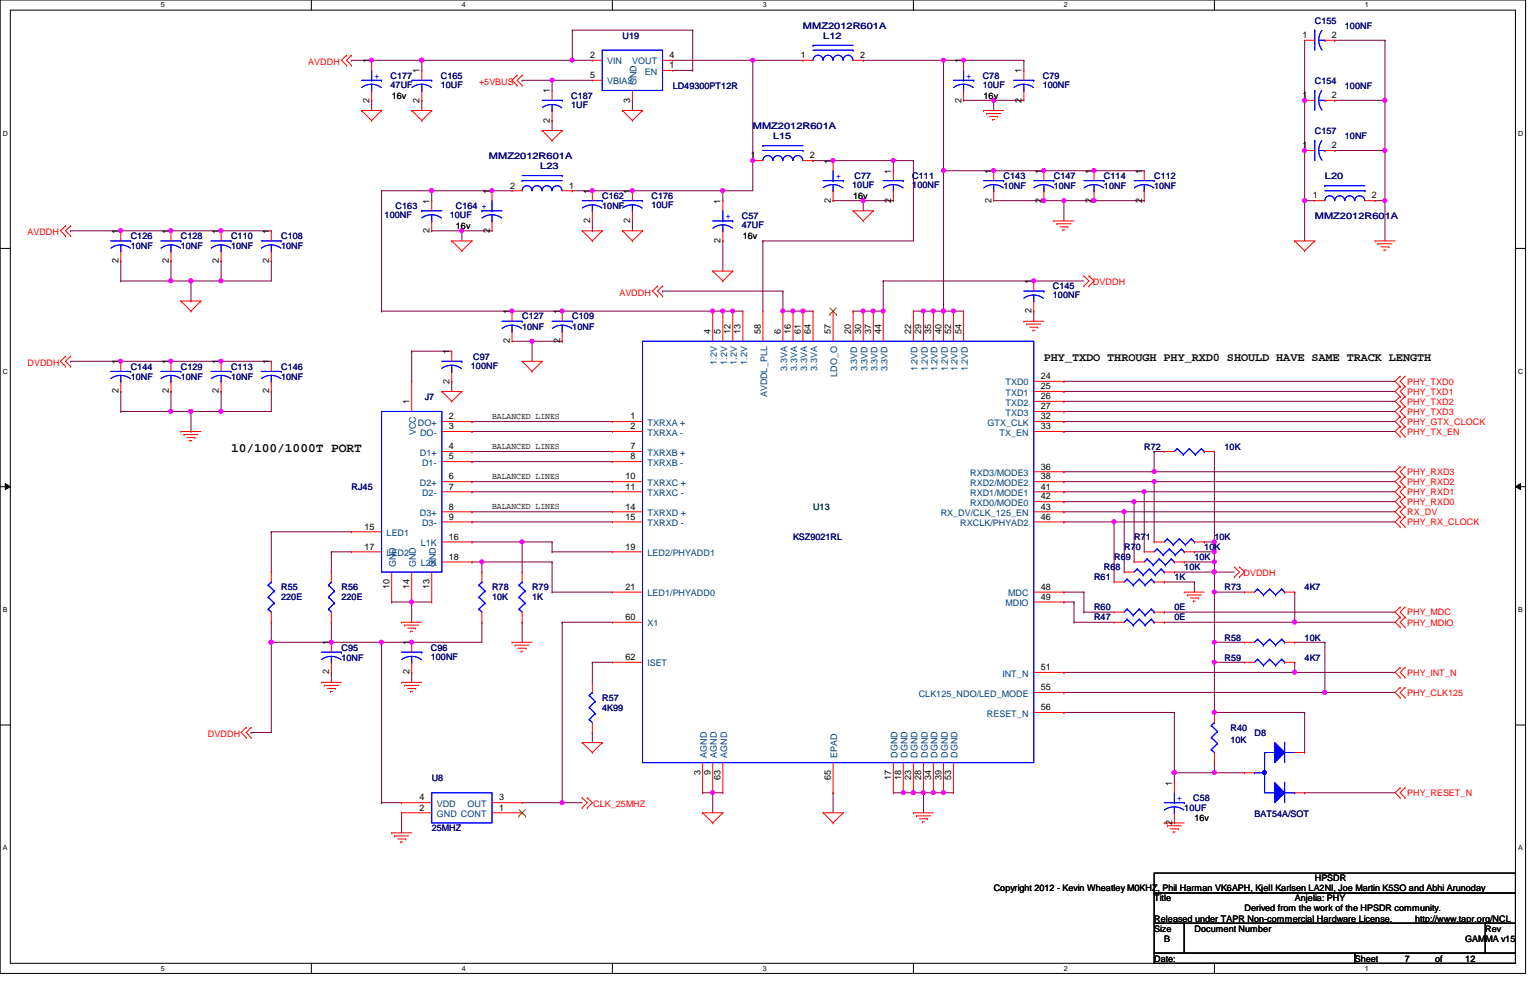
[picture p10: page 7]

PHY_TXDO THROUGH PHY_RXD0 SHOULD HAVE SAME TRACK LENGTH

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

Derived from the work of the HPSDR community.

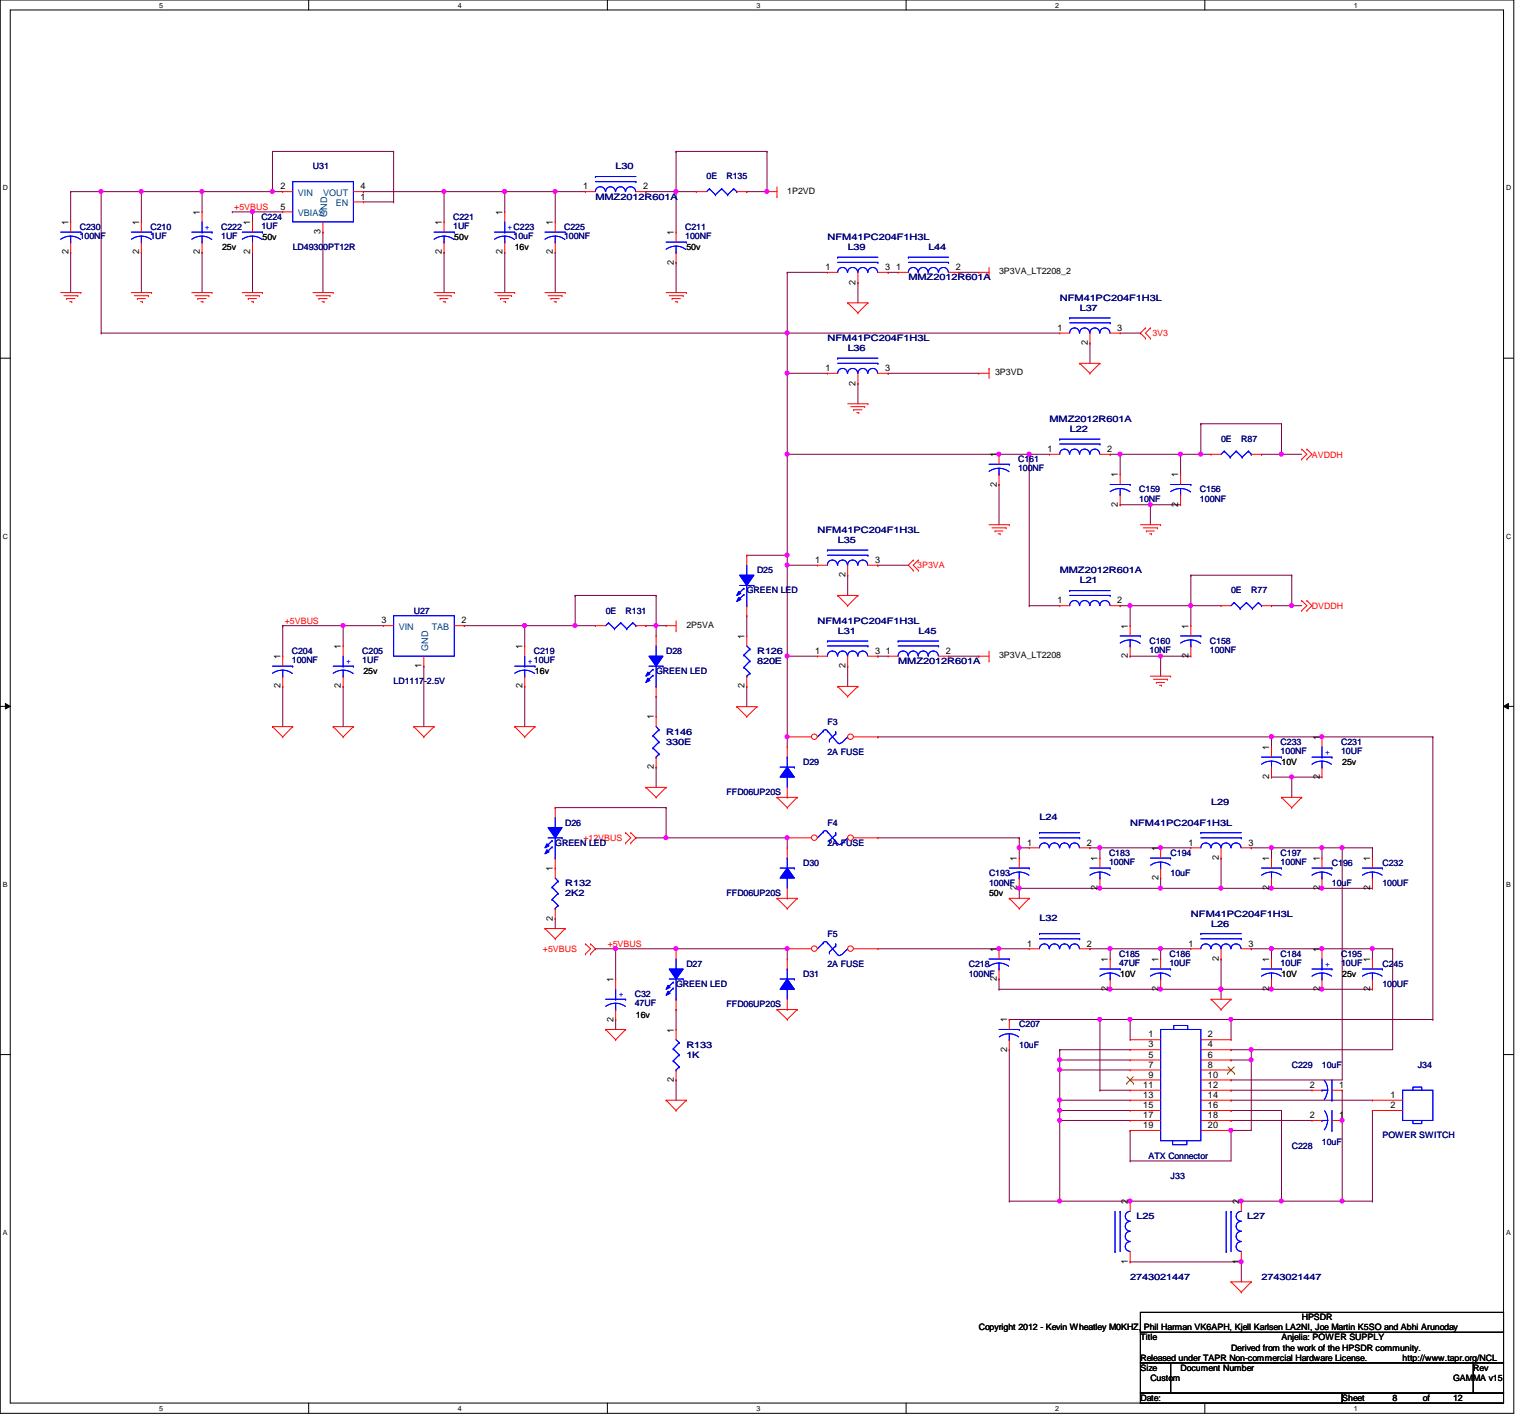
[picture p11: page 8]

17 18
19 20 | C228 10uF

### 10MHZ SELECT

### 10MHZ IN

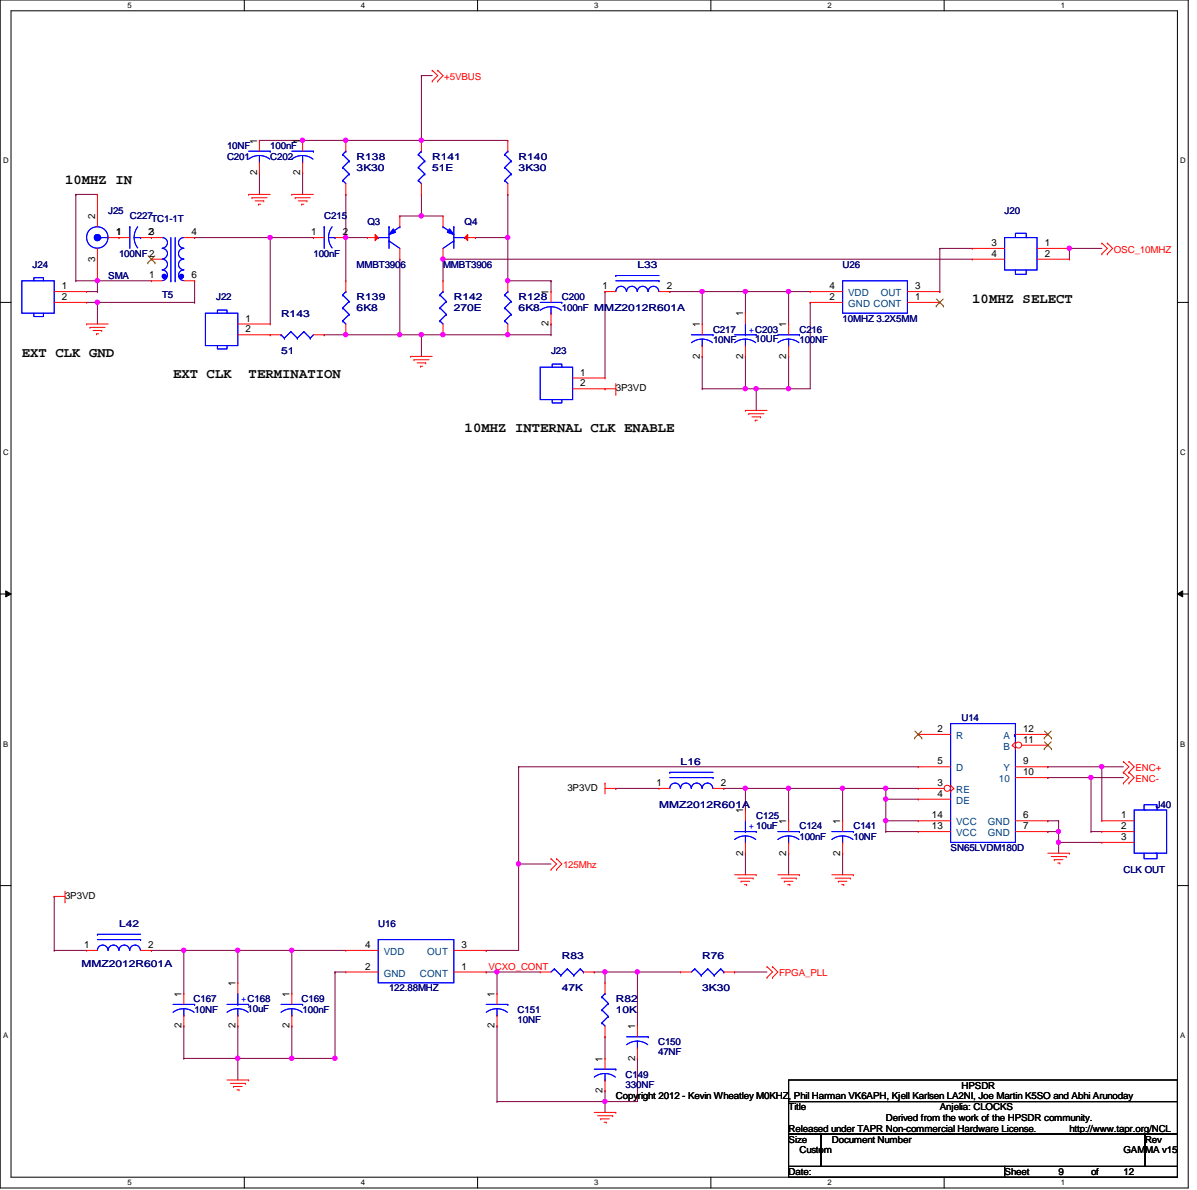
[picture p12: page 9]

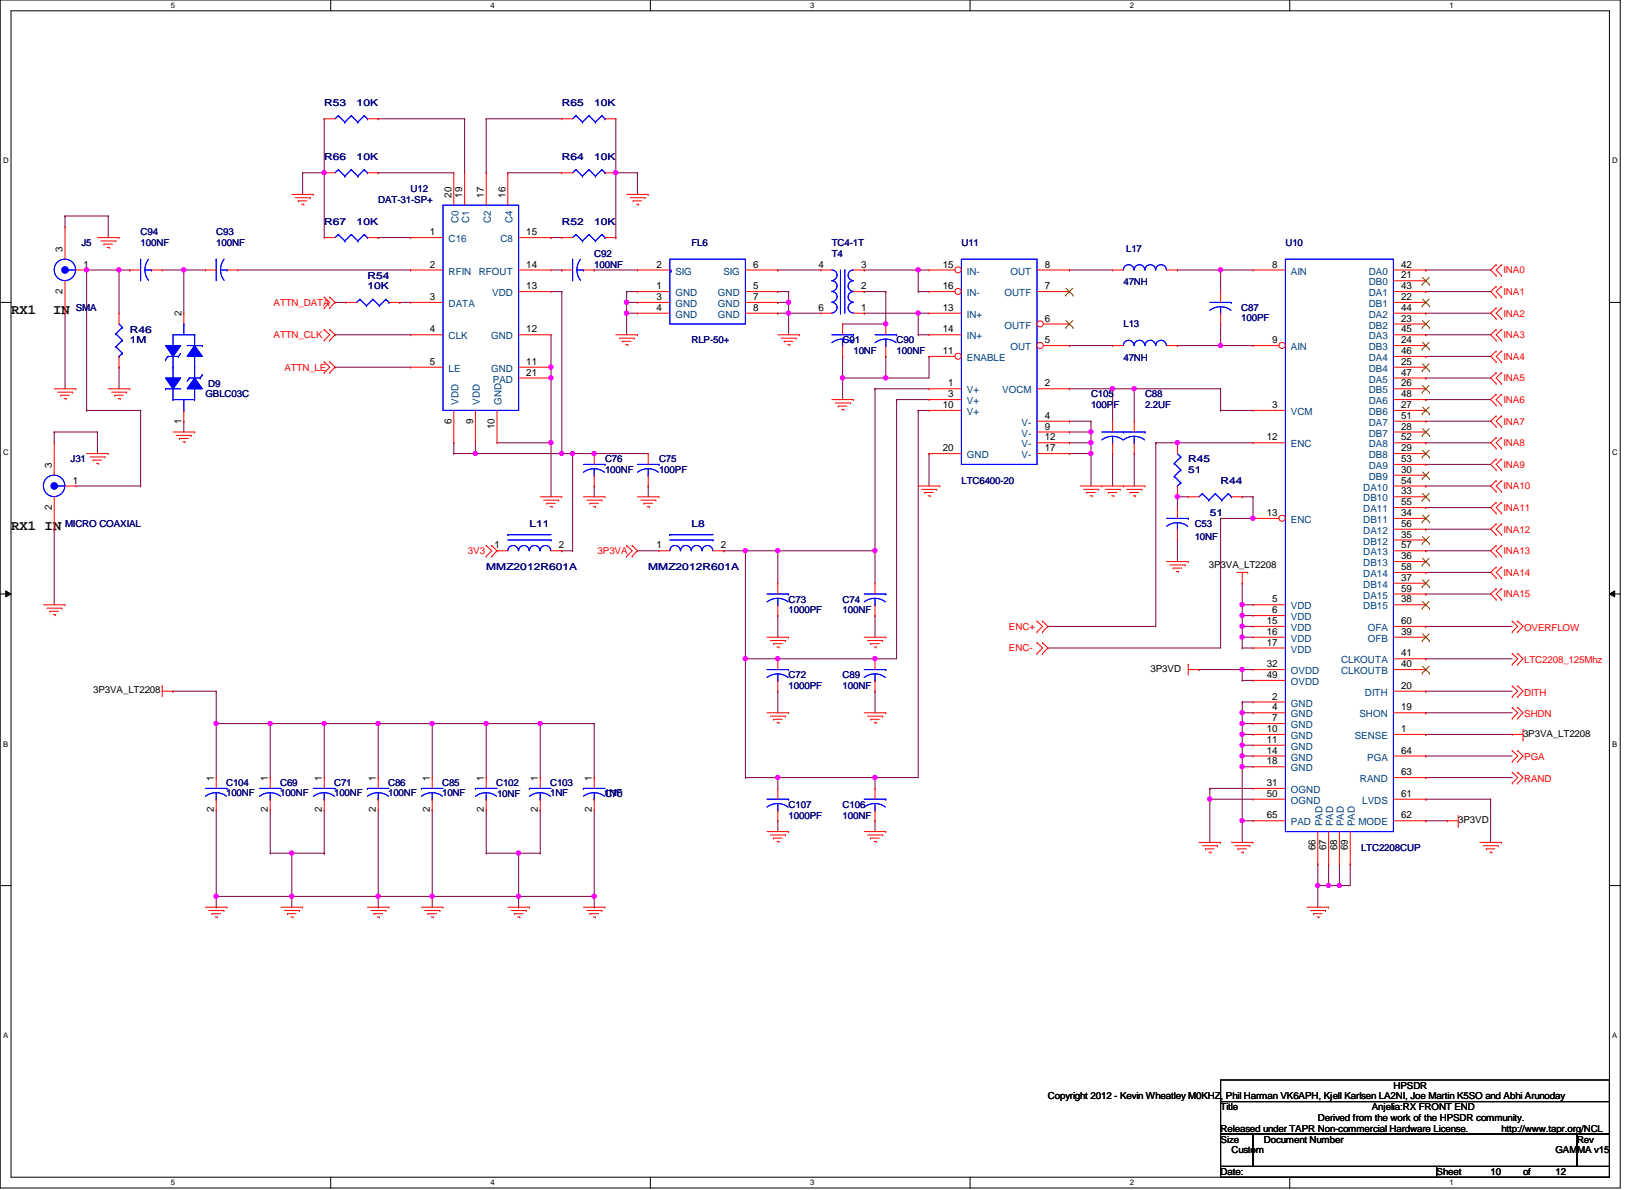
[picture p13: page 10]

Anjelia:RX FRONT END

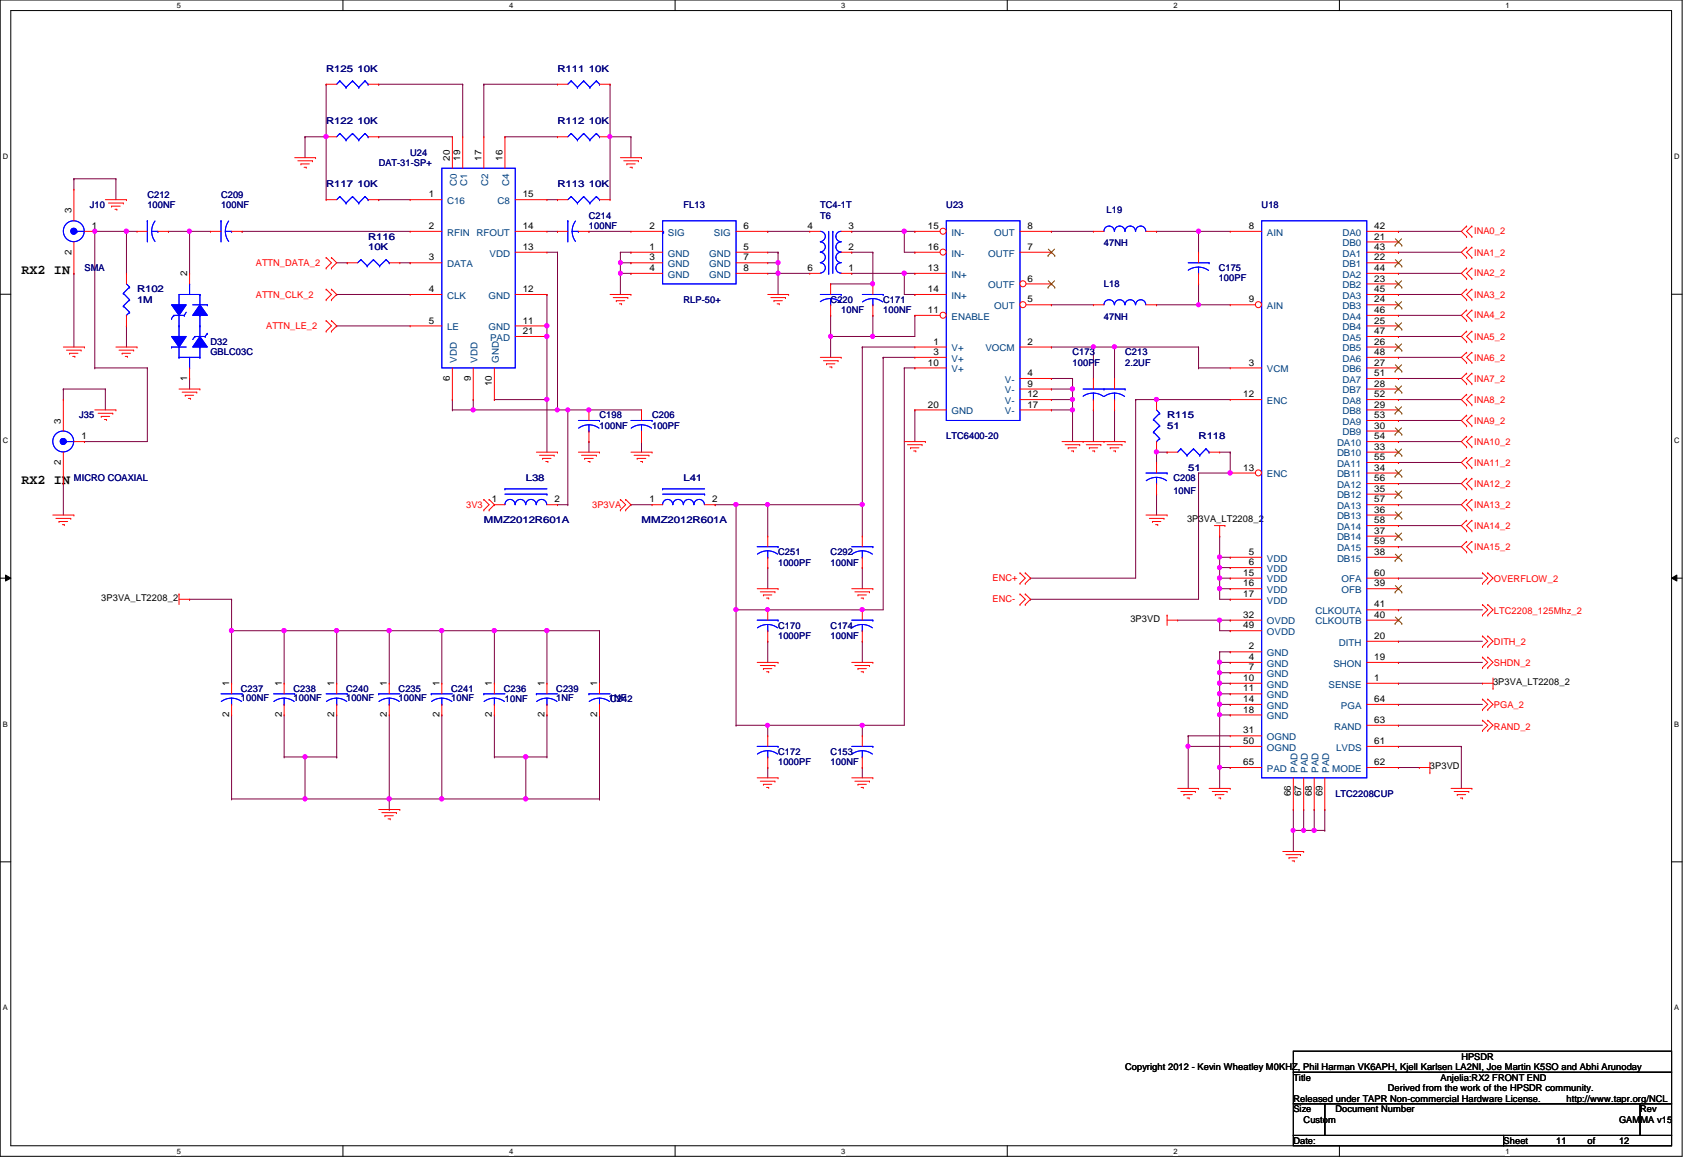
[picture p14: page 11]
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

Derived from the work of the HPSDR community.

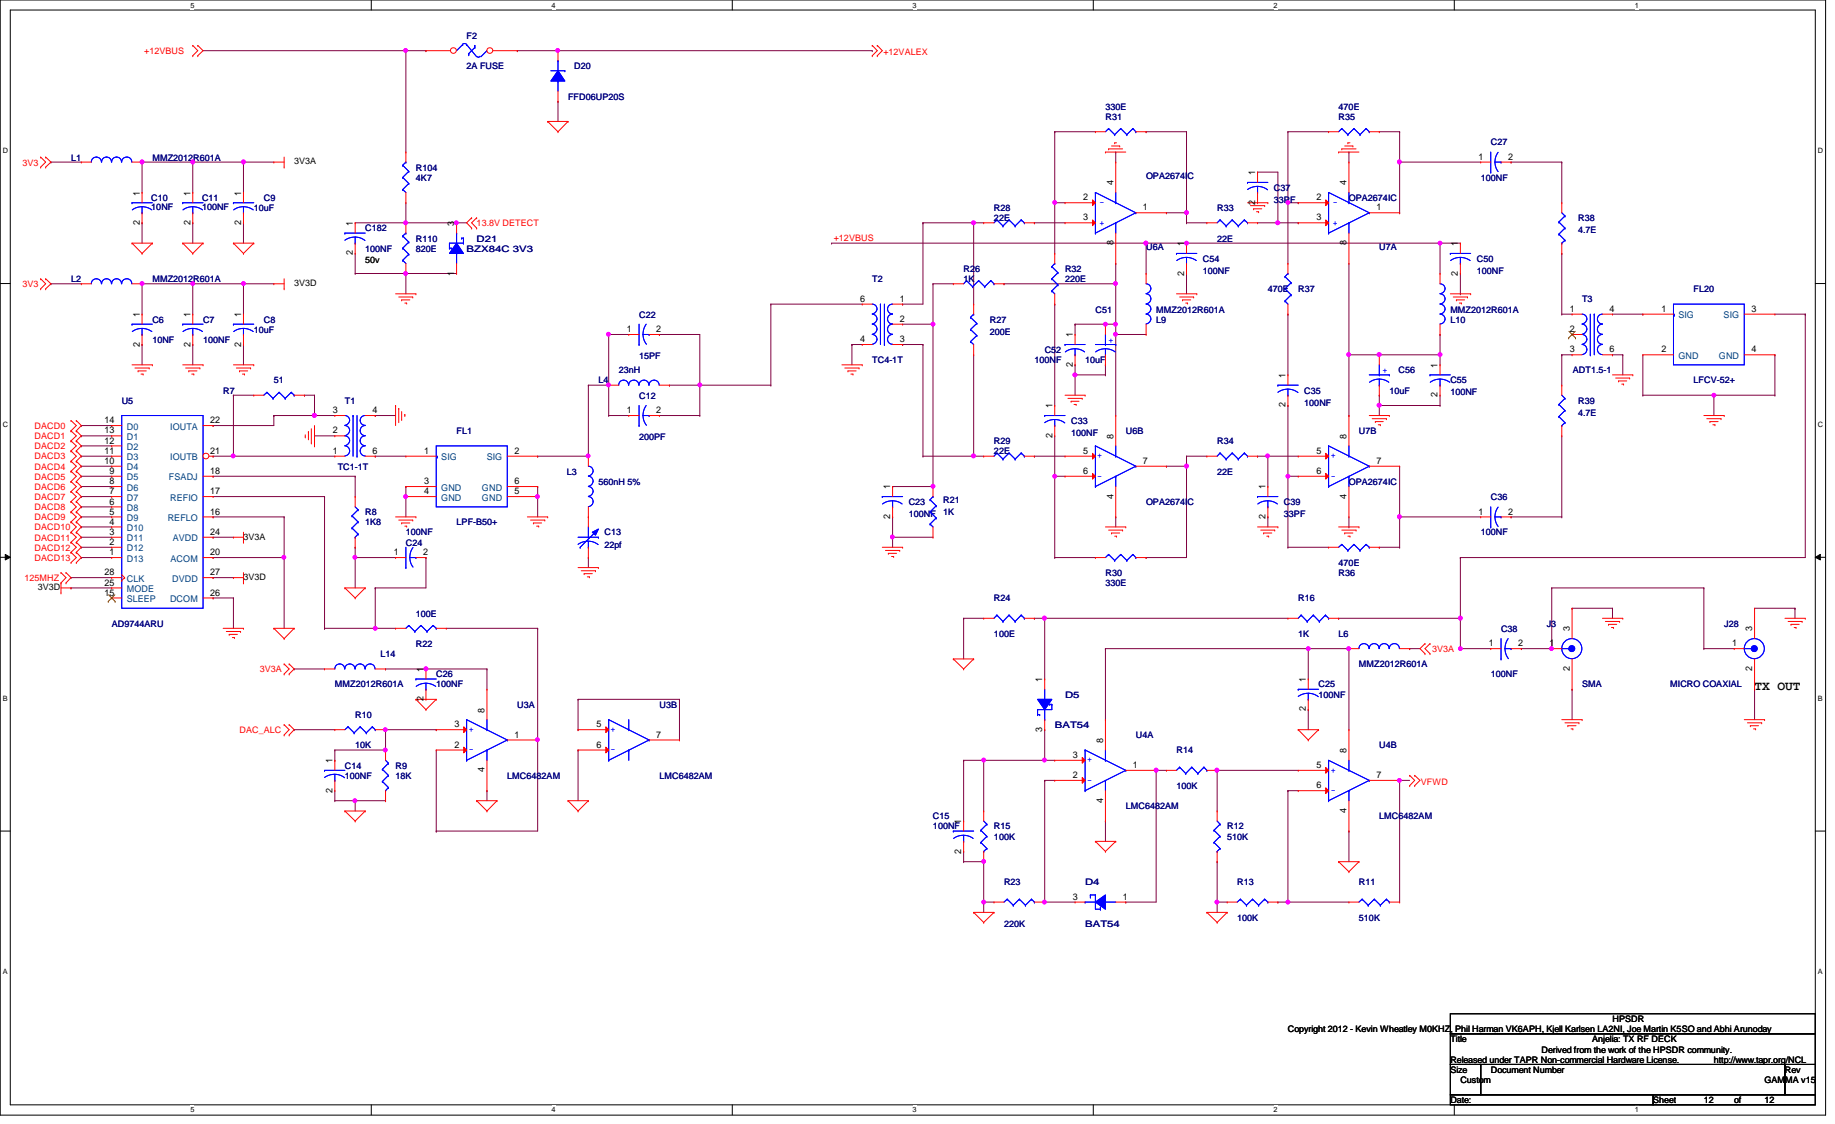
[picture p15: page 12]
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

HPSDR
Anjelia: TX RF DECK

Derived from the work of the HPSDR community.

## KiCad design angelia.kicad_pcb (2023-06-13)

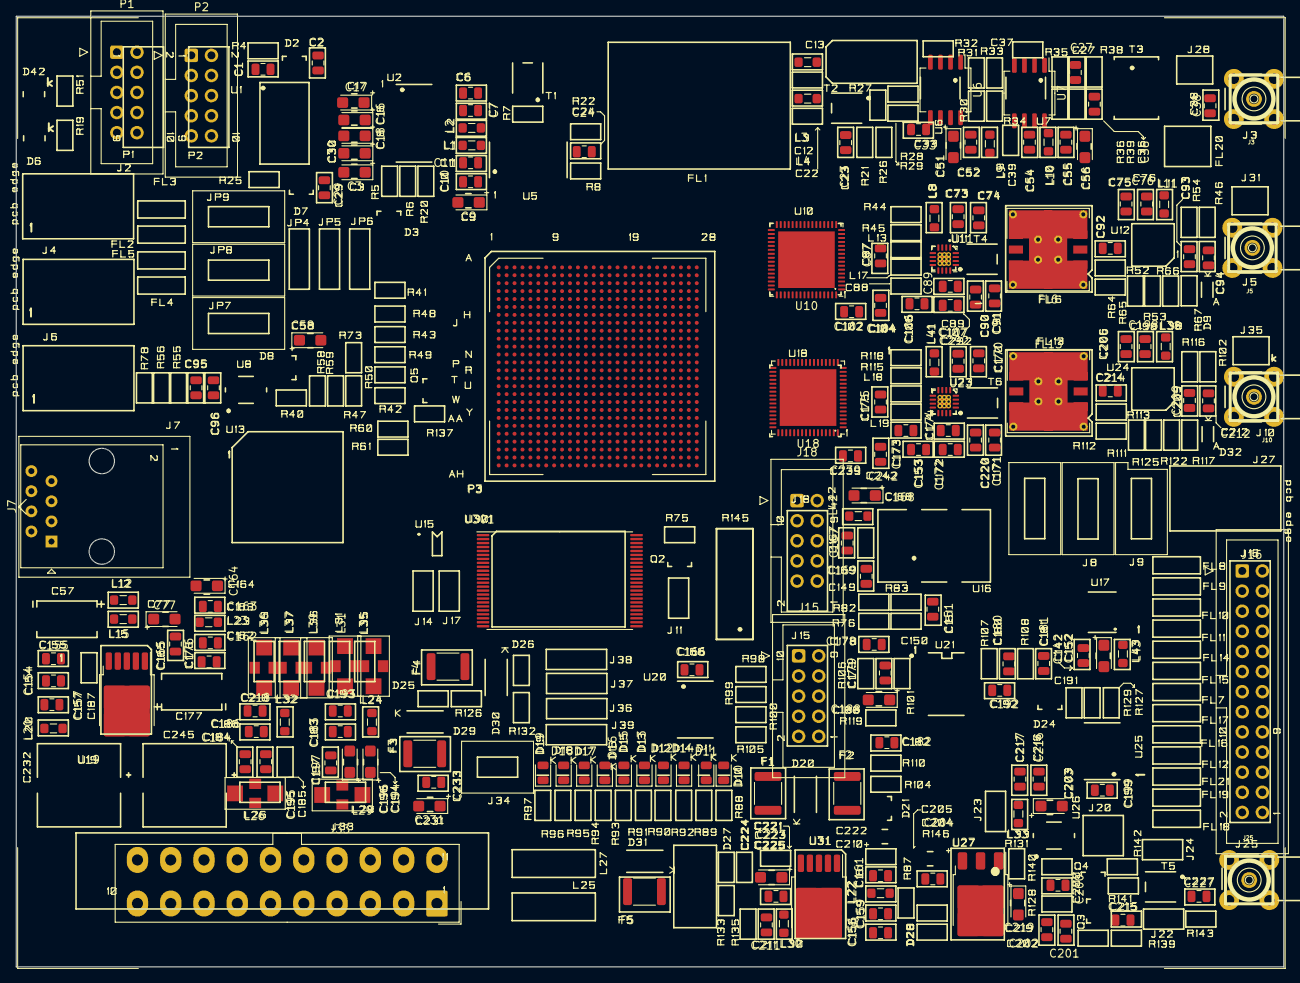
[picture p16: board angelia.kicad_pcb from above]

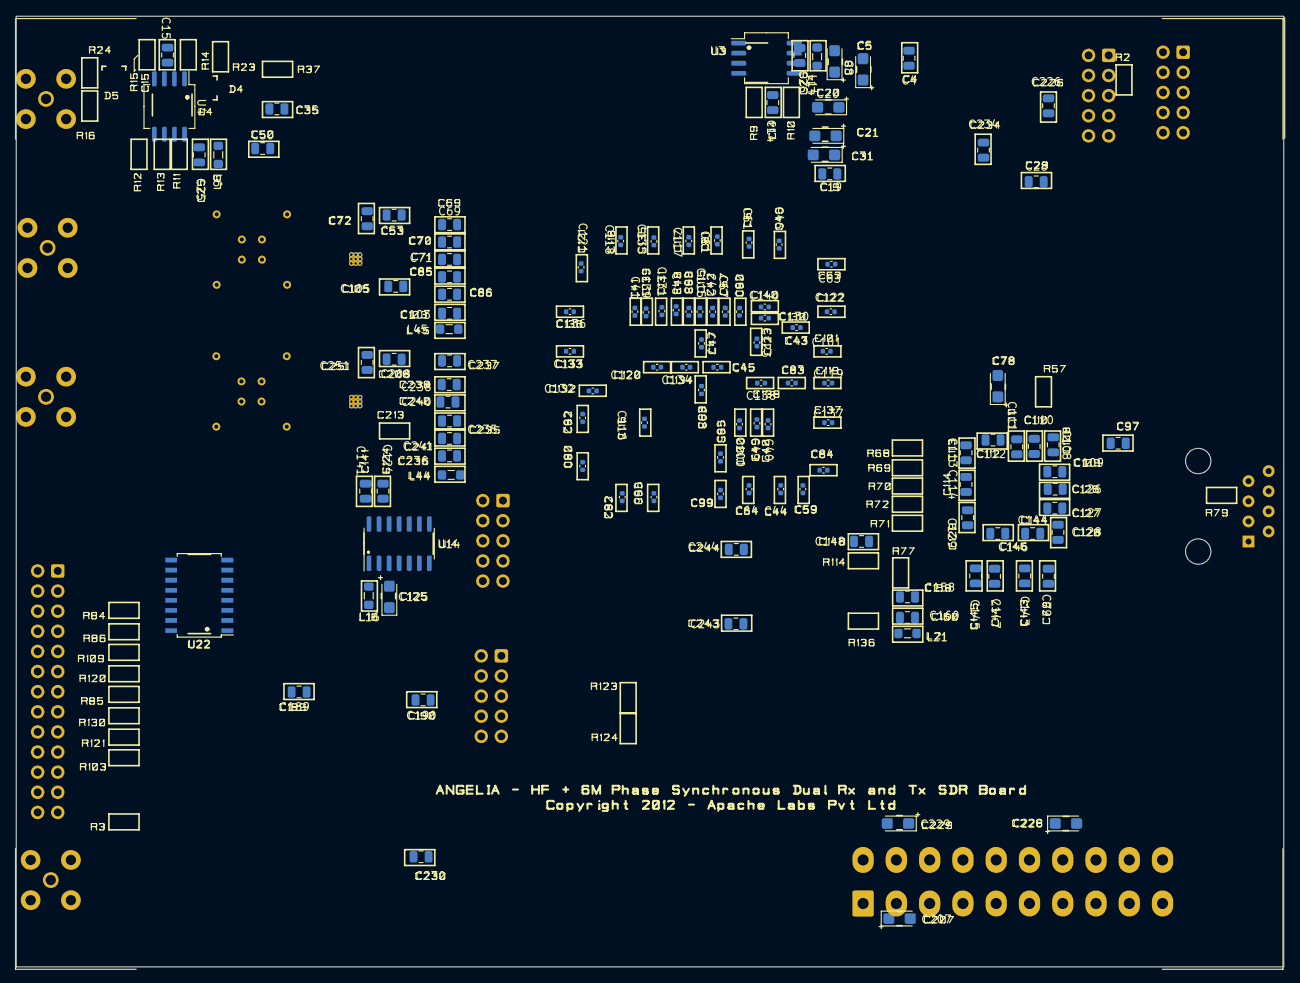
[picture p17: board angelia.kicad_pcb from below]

Board: 2 copper layers, 160.0 x 120.0 mm, 301 parts (125 on the bottom side), 15 nets, no tracks yet.

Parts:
C1, C2, C28, C29: 10p; C_0805_2012Metric
C3, C5, C8, C9, C16, C17, C18, C20, C21, C30, C31, C51, C56, C58, C77, C78, C125, C152, C164, C168, C188, C194, C196, C203, C207, C219, C223, C228, C229, C231: 10UF; CP_EIA-3216-18_Kemet-A
C4, C7, C11, C14, C15, C19, C23, C24, C25, C26, C27, C33, C35, C36, C38, C50, C52, C54, C55, C69, C71, C74, C76, C79, C86, C89, C90, C92, C93, C94, C96, C97, C104, C106, C111, C124, C142, C145, C148, C153, C154, C155, C156, C158, C161, C163, C166, C169, C171, C174, C182, C183, C189, C190, C192, C193, C197, C198, C199, C200, C202, C204, C209, C211, C212, C214, C215, C216, C218, C225, C226, C227, C230, C233, C235, C237, C238, C240, C244, C292: 100n; C_0805_2012Metric
C6, C10, C53, C85, C91, C95, C102, C108, C109, C110, C112, C113, C114, C126, C127, C128, C129, C141, C143, C144, C146, C147, C151, C157, C159, C160, C162, C167, C201, C208, C217, C220, C234, C236, C241, C243: 10n; C_0805_2012Metric
C40, C49, C60, C62, C80, C100, C132, C133: 1n; C_0402_1005Metric
C41, C43, C44, C45, C46, C47, C48, C61, C63, C64, C65, C66, C67, C68, C81, C83, C84, C98, C99, C101, C115, C116, C117, C118, C119, C120, C122, C123, C134, C135, C137, C138, C139: 100n; C_0402_1005Metric
C42, C59, C82, C121, C130, C131, C136, C140: 10n; C_0402_1005Metric
C70, C72, C73, C103, C107, C170, C172, C179, C180, C239, C242, C251: 1n; C_0805_2012Metric
C75, C87, C105, C173, C175, C206: 100p; C_0805_2012Metric
C165, C176, C178, C181, C184, C186, C195: 10u; C_0805_2012Metric
D10, D11, D12, D13, D14, D15, D16, D17, D18, D19: LED_Small; LED_0805_2012Metric
F1, F2, F3, F4, F5: Fuse_Small; Fuse_1812_4532Metric
FL6, FL13: RLP-50+; Mini-Circuits_GP1212_LandPatternPL-176
J3, J5, J10, J25: Conn_Coaxial; SMA_PINS
J7: RJ45; RJ45_Amphenol_54602-x08_Horizontal
J15, J18: Conn_02x05_Top_Bottom; IDC-Header_2x05_P2.54mm_Vertical
J16: Conn_02x13_Top_Bottom; IDC-Header_2x13_P2.54mm_Vertical
J33: ATX-20; Molex_Mini-Fit_Jr_5566-20A_2x10_P4.20mm_Vertical
L1, L2, L6, L8, L9, L10, L11, L12, L14, L15, L16, L20, L21, L22, L23, L24, L30, L32, L33, L38, L41, L42, L43, L44, L45: 220; L_0805_2012Metric_Pad1.05x1.20mm_HandSolder
L3: 560nH; L_0805_2012Metric_Pad1.05x1.20mm_HandSolder
L4: 22n; L_0805_2012Metric_Pad1.05x1.20mm_HandSolder
L26, L29, L31, L35, L36, L37, L39: FerriteBead_Small; Ferrite_LC_NFM41P
P1, P2: Conn_02x05_Top_Bottom; IDC-Header_2x05_P2.54mm_Vertical
P3: EP4CE115F780; BGA-676_27.0x27.0mm_Layout26x26_P1.0mm_Ball0.6mm_Pad0.5mm_N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
U3, U4: LMC6482AM; SO-8_5.3x6.2mm_P1.27mm
U6, U7: OPA2674IC; SO-8_5.3x6.2mm_P1.27mm
U10, U18: LTC2208xUP; QFN-64-1EP_9x9mm_P0.5mm_EP7.15x7.15mm
U11, U23: LTC6400; QFN-16-1EP_3x3mm_P0.5mm_EP1.7x1.7mm_ThermalVias
U14: SN65LVDM180D; SOIC-14_3.9x8.7mm_P1.27mm
U19, U31: TO-252-5; TO-252-5_TabPin3
U22: ULN2003A; SOIC-16W_5.3x10.2mm_P1.27mm
U27: TO-252-3; TO-252-3_TabPin2
U301: TSOP-I-48_18.4x12mm_P0.5mm

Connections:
unnamed: J33.1 (+3.3V), J33.2 (+3.3V), J33.11 (+3.3V)
unnamed: J33.4 (+5V), J33.6 (+5V), J33.19 (+5V), J33.20 (+5V)
unnamed: J33.3 (GND), J33.5 (GND), J33.7 (GND), J33.13 (GND), J33.15 (GND), J33.16 (GND), J33.17 (GND)
unnamed: U10.17 (GND), U10.64 (GND), U10.65 (GND)
unnamed: U10.31 (OGND), U10.50 (OGND)
unnamed: U10.3 (REFHA), U10.4 (REFHA)
unnamed: U10.13 (REFHB), U10.14 (REFHB)
unnamed: U10.5 (REFLA), U10.6 (REFLA)
unnamed: U10.11 (REFLB), U10.12 (REFLB)
unnamed: U18.17 (GND), U18.64 (GND), U18.65 (GND)
unnamed: U18.31 (OGND), U18.50 (OGND)
unnamed: U18.3 (REFHA), U18.4 (REFHA)
unnamed: U18.13 (REFHB), U18.14 (REFHB)
unnamed: U18.5 (REFLA), U18.6 (REFLA)
unnamed: U18.11 (REFLB), U18.12 (REFLB)

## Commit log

2023-06-10 first commit, decoupling caps ok
    [1010_ANGELIA_BOM.xls, angelia.kicad_pcb, angelia.kicad_sch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]
2023-06-10 all decoupling done
    [angelia.kicad_pcb]
2023-06-11 beginning special components
    [1010_ANGELIA_BOM.xls, angelia.kicad_pcb, angelia.kicad_sch]
2023-06-11 some more caps, still some more caps and RJ45
    [1010_ANGELIA_BOM.xls, angelia.kicad_pcb, angelia.kicad_sch]
2023-06-12 ferrites and vlsi
    [1010_ANGELIA_BOM.xls, angelia.kicad_pcb, angelia.kicad_sch]
2023-06-13 ferrites and lna
    [1010_ANGELIA_BOM.xls, angelia.kicad_pcb, angelia.kicad_sch]
2023-06-13 more vlsi, more inductances
    [1010_ANGELIA_BOM.xls, angelia.kicad_sch]
2023-06-13 all mlcc are done
    [1010_ANGELIA_BOM.xls, angelia.kicad_sch]
2023-06-13 most pull-up resistor done
    [1010_ANGELIA_BOM.xls, angelia.kicad_sch]
2023-06-14 botom side completed
    [1010_ANGELIA_BOM.xls, angelia.kicad_sch]
2023-06-14 all resistors are not futile
    [angelia.kicad_sch]
2023-06-14 that's all folks
    [1010_ANGELIA_BOM.xls, angelia.kicad_sch]
